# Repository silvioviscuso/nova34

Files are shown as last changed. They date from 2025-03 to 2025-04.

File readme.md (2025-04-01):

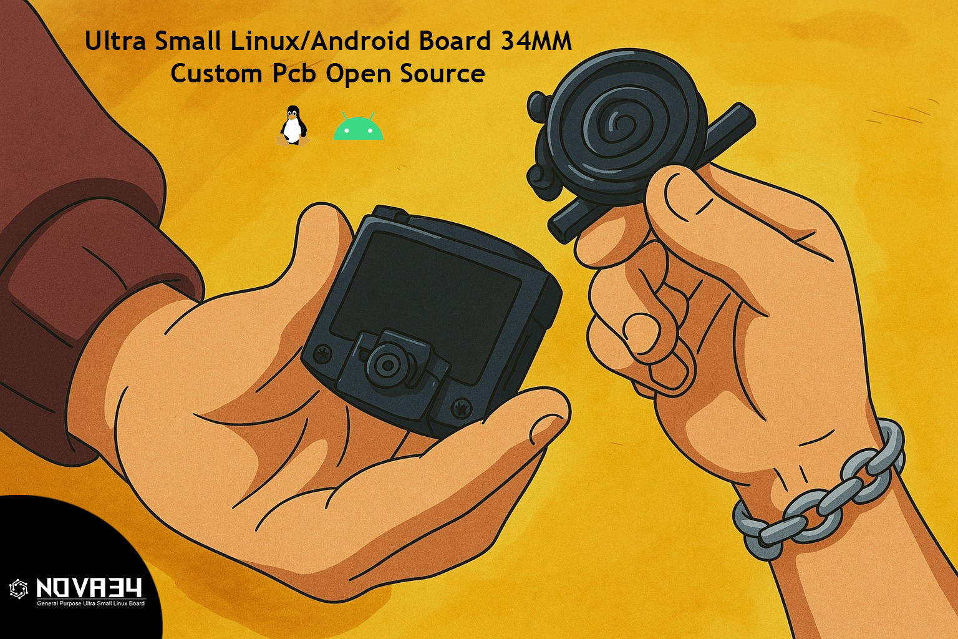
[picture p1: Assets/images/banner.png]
Preview


# NOVA34 Ultra Small Linux Board - Custom PCB Open Source 🚀
      

## Overview
This is an open-source headboard custom PCB designed in Altium for integration with the NXP MIMX8MN5DVPIZAA (I.MX 8M NANO - ULTRALIGHT 11x11MM 14nm). The board is designed to support essential peripherals such as eMMC storage, LPDDR4X RAM, WiFi/Bluetooth, camera module, and display. The design is optimized for performance and ease of assembly, with a compact form factor.

🎯 **The goal was to make it accessible to everyone—hobbyists, makers, robotics enthusiasts—without minimum order limitations.** This project follows the workflow of creating an SBC (Single Board Computer), robot board, and wearable device.

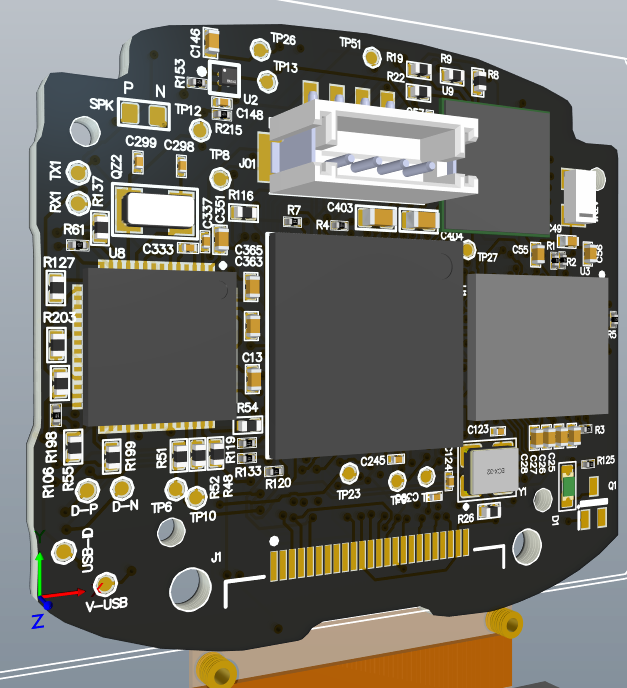
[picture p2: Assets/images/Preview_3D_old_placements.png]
Preview 1
|  | Preview 2 |
|---|---|
###### Preview from Rev_1.3

## 🛠️ Technical Specifications
### 📏 Dimensions
- **Width:** 34mm  
- **Height:** 30.946mm  
- **Thickness:** 1mm  
### Primary Components

#### Back Side
* **NXP MIMX8MN5DVPIZAA** (I.MX 8M NANO - ULTRALIGHT 11x11mm)  
* **PMIC NXP PCA9450BHNY**  
* **Antenna M310220 Kyocera Avx**  
* **ADG824BCPZ-REEL7** (For Antenna Diversity)  
* **Camera 5MP** (Autofocus, 24Pins, around 110° FOV) 
* **Connector JST B4B-ZR-SM4-TF** (1.5mm, 1 Row, 4 Contacts) – Used for power input and serial communication; the same 4-pin header must be present on the new board.  
* **USB Pads for SDM** (Serial Download Mode for firmware flashing)  
* **Speaker Pads and External Speaker**  

###### Combo Chip:  
- **Rev_1.0 to Rev_1.3:** *(Realtek) RTL8723DS* (6x6mm Wi-Fi + Bluetooth)  
- **Final Revision:** *CYW43012* (Infineon)- 106-ball WLBGA (3.76 x 4.43mm; 0.35mm pitch)  
- **Storage:** *(Kingston) 32EP16-M4FTC32-GA68* (eMMC 5.1 HS400 + LPDDR4X 144-FBGA)  

#### Front Side
* **IMU BMI160** Bosch  
* **Display ST0103A2W-WSNLW-F** Santek  
* **NC7SP125P5X** Onsemi Fairchild
* **MAX98357AETE+T**  Analog Device

---

## 🔧 Design and PCB Progress  
#### Revision Notes

In **Rev_1.0 to Rev_1.3**, the process included several testing phases to assess the engineering validity of component research and selection.  

- During this phase, we identified the **ADP191ACBZ-R7**, an ultra-compact high-side load switch. This component could be useful for managing power distribution efficiently, providing controlled power switching to different subsystems while offering short-circuit and overcurrent protection.

- With the latest revision, we implemented the **ADP191ACBZ-R7**,  Now, the **ADP191ACBZ-R7** also provides **ESD protection**, which was previously required only for USB connections. To ensure stable voltages, we added protection for the **CAMERA, DISPLAY, and WIFI module** using the **ADP191ACBZ-R7**. Additionally, we included a differential pair for the USB connection. The **ADP191ACBZ-R7** is now connected with **GPIO pins**, allowing it to be enabled and disabled as needed.

- Additionally, we replaced the **RTL8723DS (6x6mm)** combo-chip Wi-Fi/Bluetooth. Its footprint fit comfortably in the upper-right section of the back-side of the board. However, after further evaluation, we found a better and more compact alternative: the **CYW43012**, which offers improved efficiency and performance.  

- Initially, we also considered the **AMA3B1KK-KBR-B0 (Apollo3 Blue)**, but in the end, we opted for the **CYW43012** as the best choice for this design. That said, we could still explore **future variants** incorporating different wireless solutions based on project needs.  

- Placement and optimization trials were conducted, along with numerous other evaluations, successfully achieving the set objectives.  

- Additionally, for the **RF switch component**, we utilized the **ADG824BCPZ-REEL7** instead of the **QPC8020QTR13 (Qorvo, RF switch)** to support **Antenna Diversity**, which includes both traced and ceramic antenna configurations.  

Now, with the **final revision**, the **schematic is fully defined and accurate**, allowing for a more streamlined approach to PCB design in **High-Speed Design & Signal Integrity**.

---

### Test in old revisions component placements
| Top Signal | Top SilkScreen | Solder Mask |
|---|---|---|
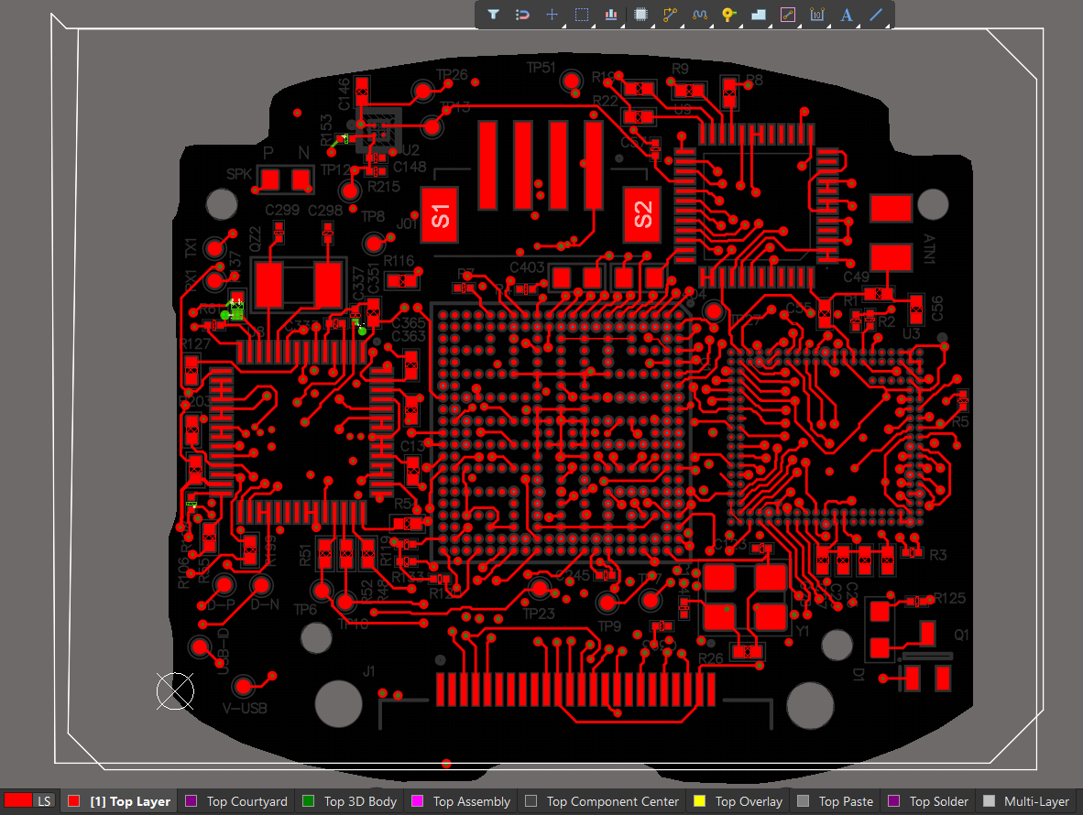
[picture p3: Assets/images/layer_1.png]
Layer 1
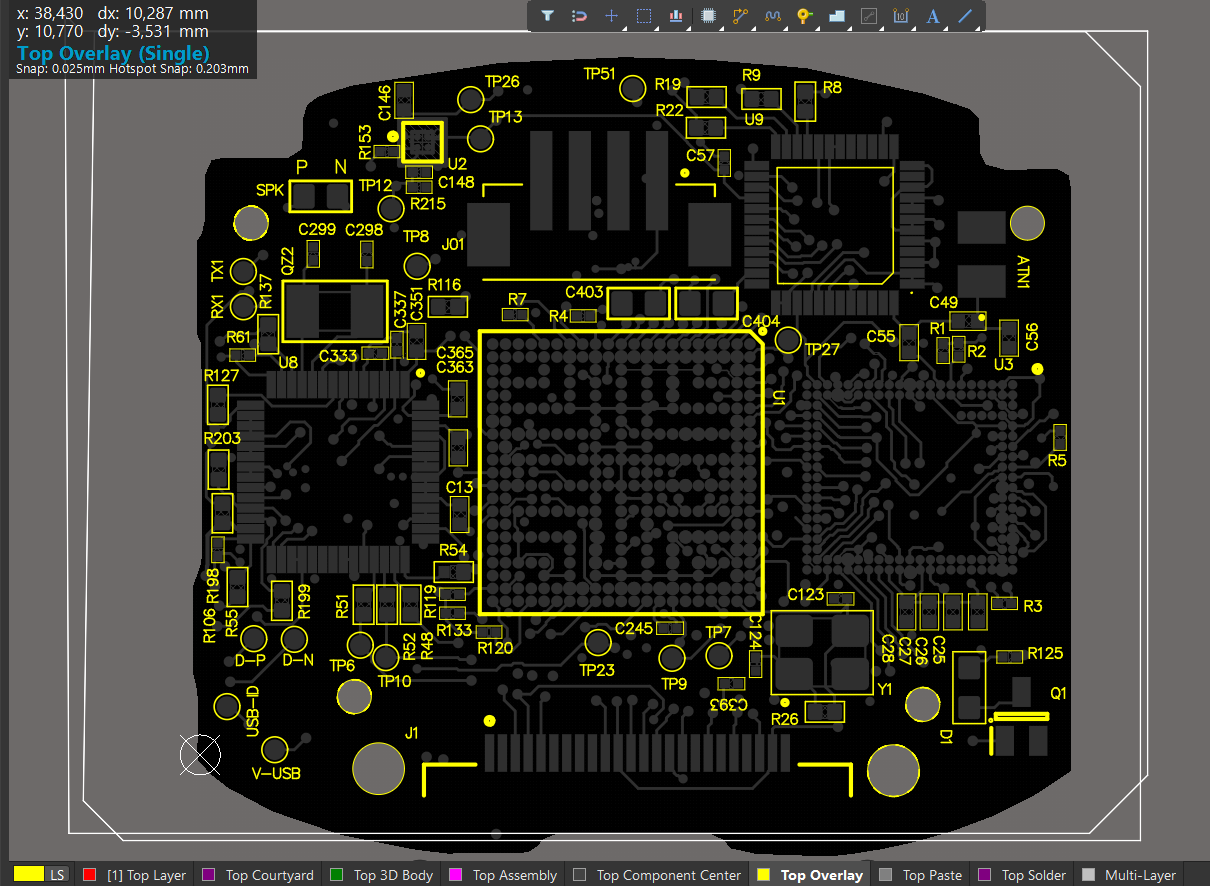
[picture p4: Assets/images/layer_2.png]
Layer 2
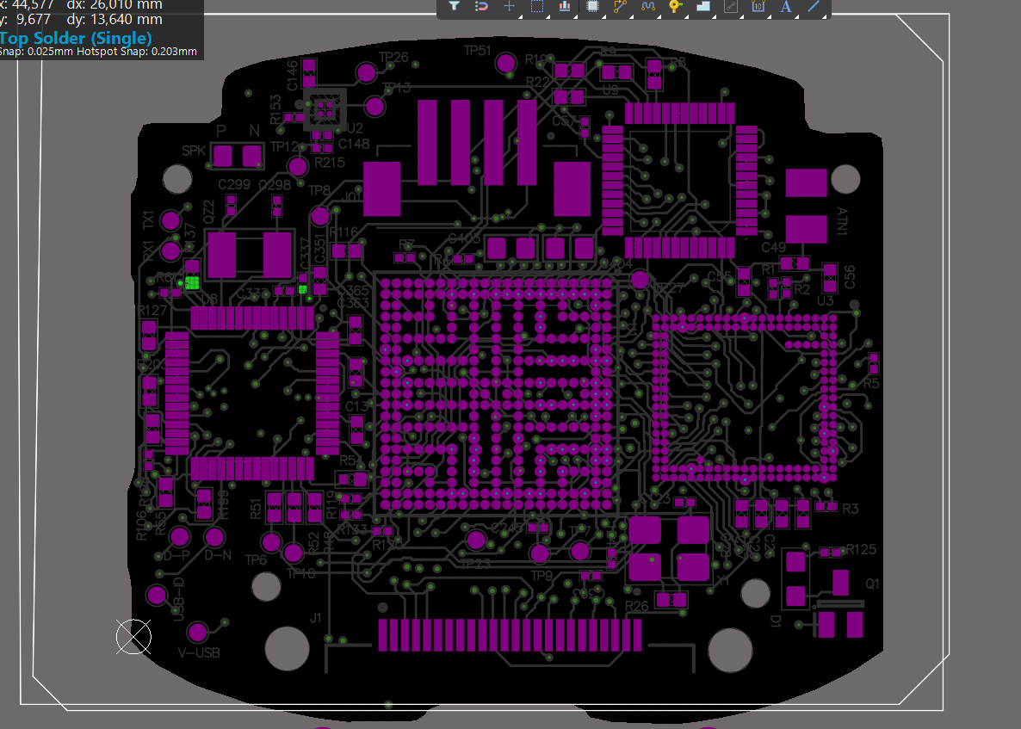
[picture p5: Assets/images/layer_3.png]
Layer 3
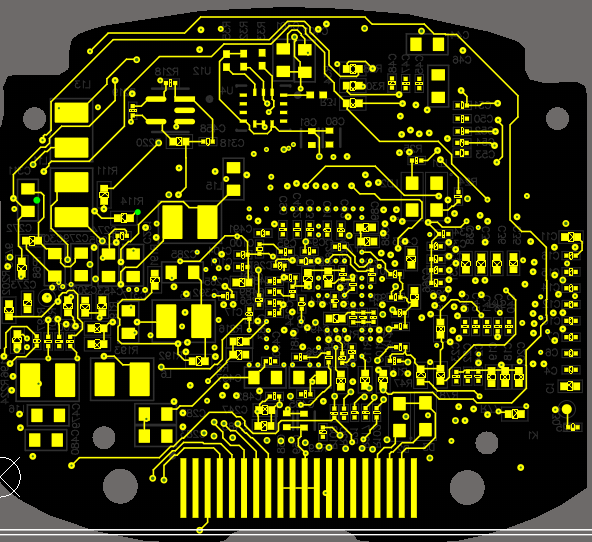
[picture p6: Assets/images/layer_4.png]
Layer 4
|  |  |  |  |

##### Old preview 3D
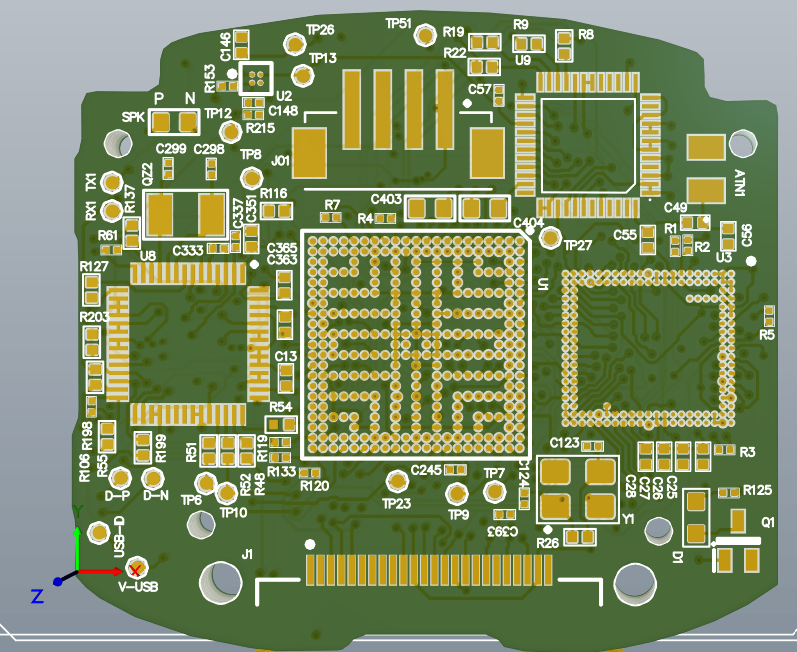
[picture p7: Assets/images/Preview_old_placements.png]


--- 

#### Status:  
**Schematic:** ██████████ 100% (Complete)  
**PCB:** ███░░░░░░░░ 30% (In Progress)

---

## 📋 Component List & Costs (Prices may vary depending on the supplier, market trends or other reasons)
📄 A detailed spreadsheet with reference links (primary components) has been created. You can find it here: [Components/components.md](Components/components.md).
| **Componente** | **Part Number** | **Price (€)** |
|---|---|---|
| **Processor** | MIMX8MN5DVPIZAA  (NXP) | 22.14 |
| **Memory ePOP** | 32EP16-M4FTC32-GA68 (KINGSTON) | 25.35 |
| **Connector** | B4B-ZR-SM4-TF (JST) | 0.66 |
| **PMIC** | PCA9450BHNY (NXP) | 4.11 |
| **IMU** | BMI160 (BOSCH) | 1.46 |
| **WiFi/Bluetooth**  | CYW43012TC0KFFBH  (Infineon Technologies) | 10.00 |
| **Antenna** | M310220  (KYOCERA AVX) | 0.91 |
| **Display** | ST0103A2W-WSNLW-F  (SANTEK DISPLAY SPECIALIST) | 31.84 |
| **DAC** | MAX98357AETE+T (ANALOG DEVICE) | 4.50 |
| **External Speaker**| RS PRO 8Ω 0.5W Miniature Speaker 20mm (RS PRO) | 15.00 |
| **RF SWITCH** | ADG824BCPZ-REEL7 (ANALOG DEVICE) | 3.00 |
| **Buffer** | NC7SP125P5X (Onsemi Fairchild) | 0.70 |
| **Camera** | 5MP MIPI Camera Module – MCM5M120M6F1 (IADY) | 15.00 (USD) |
| **Power Switch** | ADP191ACBZ-R7 (ANALOG DEVICE) | 1.91 (USD) |
| **PCB + Stencil**  | JLPCB | 120-150 |

---

### Requirements:
- Software: Altium Designer v24.6.1 or later. (Fully compatible with **MacOS via Parallels Desktop with Windows 11 ARM**).

---

## 🚀 Getting Started  

#### The official documentation can be found in the nova34_docs repository at the following link: [nova34-docs.vercel.app](https://nova34-docs.vercel.app)

1. **Download the Design Files**  
   - [GitHub Repository](https://github.com/silvioviscuso/nova34)  
   - Open Project group file (**.Nova.DsnWrk**)

2. **Schematics, Library and Netlist**  
   - At this stage, the **schematic files, library, and netlist** are fully completed and ready for review.  
   - The **PCB design is still in progress**, and full assembly instructions will be provided once completed.  

3. **Upcoming Documentation** *(to be released soon)*  
   - Complete **PCB assembly guide** for both factory production and **homemade/hobbyist assembly**.  
   - **List of required tools** for manual assembly.  
   - **Technical drawings** and reference materials.  
   - **Decals and labeling** for easy identification.  
   - Additional resources to streamline the build process.  
---

## 🤝 Contributing
This project is open-source, and contributions are welcome! You can help by:
- Suggesting improvements or fixes.
- Testing and documenting.
- Creating alternative designs or add-ons.
- Developing a custom jig with pogo pins.
- Generating an interactive BOM (HTML/PDF).
- Designing a high-speed circuit with signal integrity considerations.
- Performing thermal simulations.

We encourage you to submit a pull request with your contributions to help improve the project!

### How to Submit a Pull Request
1. **Fork the repository** to your GitHub account.
2. **Create a new branch** dedicated to your revision (e.g., `Rev_1.4-fix-component-placement`).
3. **Make your changes** and ensure everything works as expected.
4. **Commit and push** your changes to your forked repository.
5. **Open a pull request** with a clear description of the modifications and improvements.

## ⭐ Star project and stay tuned for updates!

## 📜 License
This project is released under the **Creative Commons Attribution-NonCommercial 4.0 International (CC BY-NC 4.0) License**. You are free to modify and share the design, but **commercial use is not permitted**.

---
## 🔗 Other Similar Projects  

If you're interested in open-source compact boards and embedded devices, you might also find this project useful:  

 Chip Icon&nbsp; **[ESP32-REACTJS-DEVKIT](https://github.com/silvioviscuso/ESP32-REACTJS-DEVKIT)** – An **ultra-compact 35mm board** based on **ESP32-DOWDQ6 + 16MB**, perfect for IoT projects and ReactJS development.  

---

For any questions or discussions, feel free to open an issue on GitHub or contact me directly.

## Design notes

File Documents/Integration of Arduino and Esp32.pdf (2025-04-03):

### Integration of Arduino with MX8M

Integrating Arduino into this project isn’t about replacing the i.MX 8M Nano; it’s about adding an accessible, flexible layer that our community can readily work with. Here’s how Arduino relevance is achieved:

1. Task Offloading & Peripheral Expansion:
Arduino boards can handle low-level, time-critical tasks (like sensor readings, motor control, and managing extra GPIOs) so the main Nano can focus on high-performance tasks such as multimedia processing. This means hobbyists and makers can add new peripherals (sensors, actuators, etc.) and control them via Arduino, leveraging its rich library ecosystem.

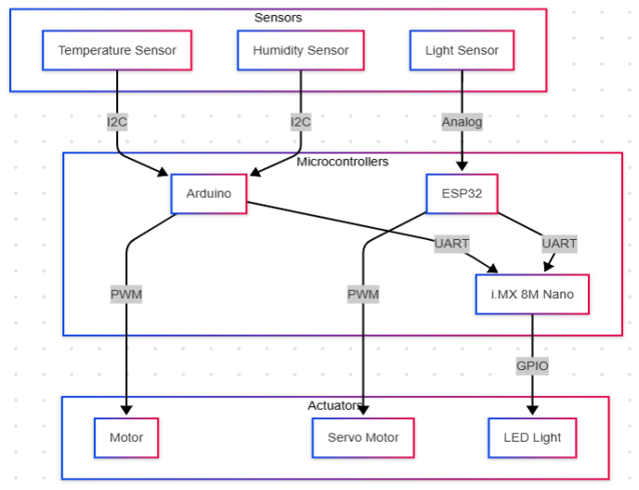
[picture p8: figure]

2. Ease of Use & Rapid Prototyping:
Arduino’s well-documented programming environment makes it straightforward for the community to experiment, develop new applications, and quickly integrate additional functionalities without having to dive into complex C-code for the Nano. For instance, you can use a dedicated Arduino-compatible header (via a JST connector) for serial communication, allowing users to send commands, debug, or control aspects of the board easily.
3. Interoperability:
The design allows the Arduino (or even an ESP32 module) to act as a co-processor. This modular approach means that Arduino can be used to bridge legacy projects or quick prototypes with the high-performance NOVA34 system. Whether it’s handling local sensor data or managing simple automation tasks, the Arduino integration makes the platform more accessible to a broader community.

### Arduino Integration

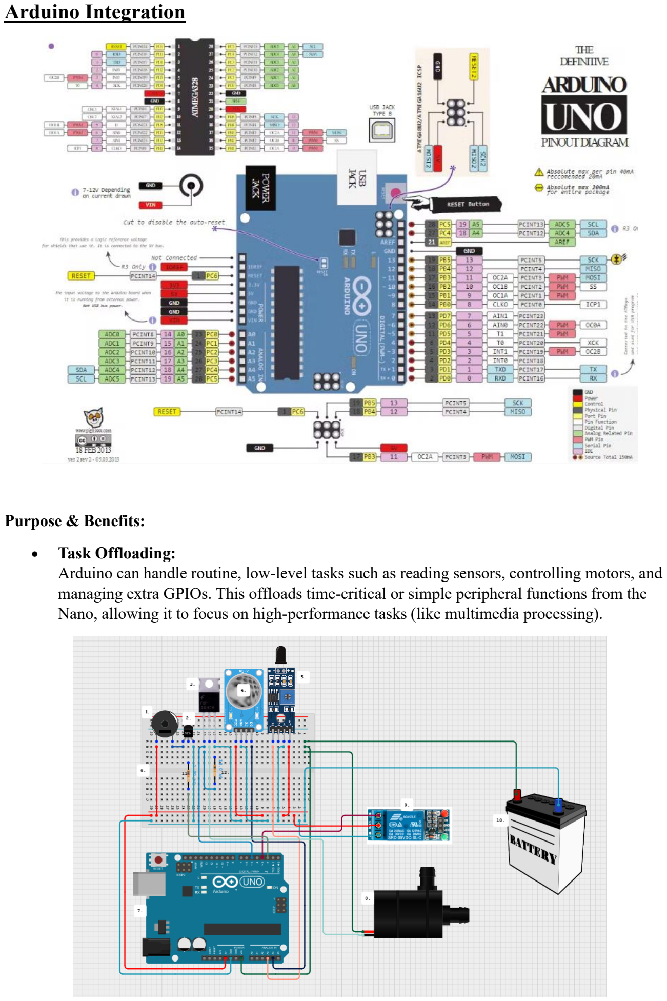
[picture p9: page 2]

Purpose & Benefits:

- Task Offloading:
Arduino can handle routine, low-level tasks such as reading sensors, controlling motors, and managing extra GPIOs. This offloads time-critical or simple peripheral functions from the Nano, allowing it to focus on high-performance tasks (like multimedia processing).

- Rapid Prototyping:
Arduino’s well-documented ecosystem, familiar IDE, and rich library support make it easy for hobbyists to quickly develop and test new ideas. Users can rapidly add functionalities (e.g., environmental sensing, actuator control, or even simple user interfaces) without diving into complex low-level code.
- Interoperability:
Arduino modules can act as co-processors, handling specialized tasks and communicating with the Nano via serial (UART), SPI, or I²C interfaces. For example, a dedicated Arduino header (using a JST connector) can allow users to send serial commands, debug the system, or control external peripherals independently.

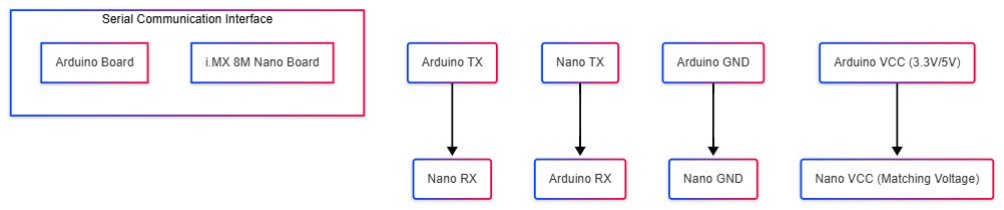
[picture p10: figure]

What Arduino Can Control:

- Sensors and Actuators: Arduino can manage additional sensors (temperature, humidity, light, etc.) and drive actuators (motors, LEDs, relays) using its digital I/O, analog inputs, and PWM outputs.
- User Interfaces: It can handle button inputs, LED displays, or even small OLED screens to create custom user interfaces or status indicators.
- Communication Protocols: Arduino can take over I²C, SPI, or UART communications for non-critical peripherals, freeing up the Nano’s resources.

### 2. ESP32 Integration

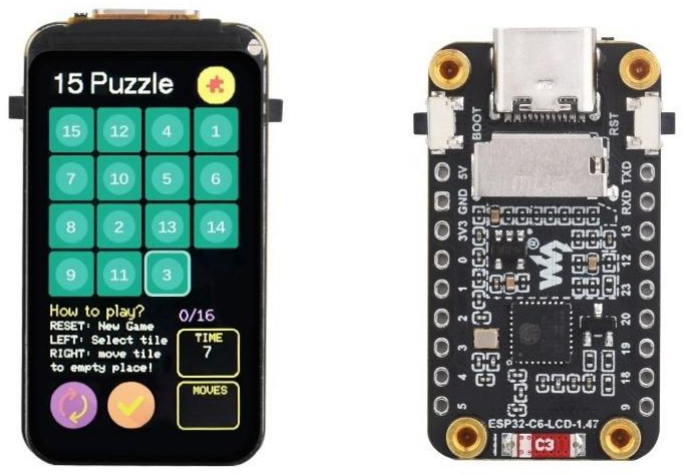
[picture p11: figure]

Purpose & Benefits:

- Enhanced Wireless Connectivity:
While the CYW43012 handles Wi-Fi/Bluetooth for the main system, the ESP32 can serve as a backup or additional communication channel. Its built-in Wi-Fi and Bluetooth, along with robust network libraries, make it ideal for IoT applications.

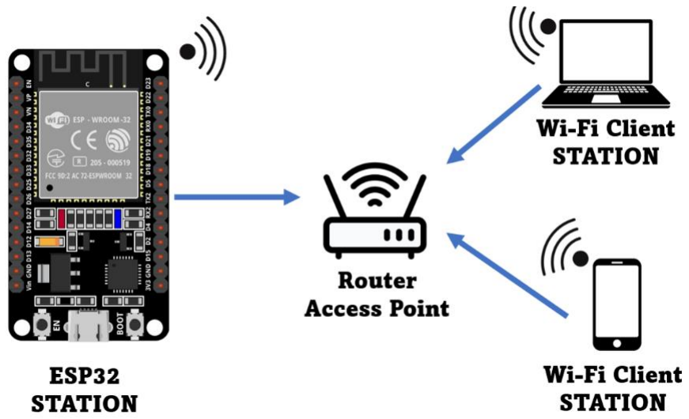
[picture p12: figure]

- Edge Processing:
The ESP32’s dual-core processor can perform local data processing, filter sensor data, or run lightweight machine learning algorithms at the edge. This reduces latency and decreases the processing load on the Nano.
- Intermediary Role:
ESP32 can act as a gateway between the NOVA34 and cloud services, managing local communication protocols, buffering data, or handling over-the-air updates.

What ESP32 Can Control:

- Real-Time Sensor Data Processing: The ESP32 can gather data from sensors connected via I²C, SPI, or analog inputs, process it locally, and then forward critical information to the Nano.

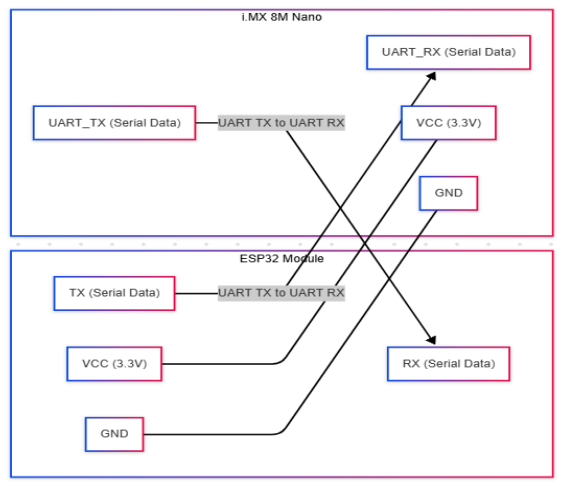
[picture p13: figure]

- Local User Interfaces: ESP32 can drive small displays, manage touch inputs, or even handle audio tasks for voice commands.
- Secondary Communication Interfaces: It can manage additional interfaces like secondary UARTs or SPI buses, especially useful when connecting legacy devices or creating a modular expansion system.

### 3. System Integration & Interfaces

Dedicated Expansion Connectors:

- Serial/JST Connector:
A dedicated 4-pin JST header on the NOVA34 board can provide power and serial communication (TX, RX) between the Nano and an Arduino or ESP32 module. This interface allows for command/control, debugging, and firmware updates.
- I²C/SPI Buses:
Shared I²C or SPI buses enable both Arduino and ESP32 to interface with external sensors and modules. Level shifting might be necessary if voltage domains differ.
- GPIO Expansion:
Additional GPIO headers can be routed to allow these co-processors to control or monitor extra peripherals without interfering with the Nano.

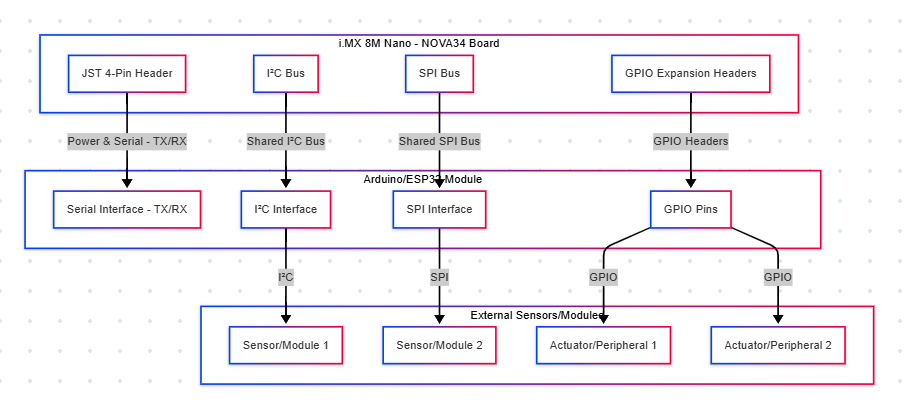
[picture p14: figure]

Software & Communication:

- Inter-Processor Protocols:
Define a clear protocol (for example, using serial commands, MQTT over Wi-Fi, or SPI-based communication) so that Arduino/ESP32 can reliably send data to, or receive commands from, the i.MX 8M Nano.
- Firmware Examples:
Provide sample sketches and libraries that demonstrate how to offload tasks like sensor reading, motor control, and local processing to Arduino/ESP32, with results then communicated back to the main system.
- Community Collaboration:
Document these interfaces extensively in the project’s GitHub repository to encourage community contributions, making it easier for Arduino and ESP32 developers to build on the platform.

### 4. Future Possibilities for Community Extensions

- Modular Sensor Hubs:
Create Arduino shields or ESP32 modules for specific functions (e.g., environmental monitoring, robotics control) that can plug into the NOVA34 system.
- Local Data Processing:
Develop projects where the ESP32 performs preliminary data processing (like filtering or aggregation) before handing off data to the Nano, improving system efficiency.
- Interoperability Projects:
Leverage the familiarity of Arduino and the advanced capabilities of ESP32 to enable projects that span both communities, such as remote monitoring systems, IoT gateways, or hybrid robotics platforms.
- User Interface Development:
Build additional user interface modules that can be controlled independently via Arduino/ESP32, enabling a more versatile, multi-touch, or even voice-controlled system.

Conclusion

Integrating Arduino and ESP32 into the NOVA34 project enriches the platform by offloading simpler, real-time tasks and expanding peripheral connectivity. This approach not only reduces the load on the high-performance i.MX 8M Nano but also opens up a broad range of possibilities for rapid prototyping, community-driven innovation, and modular expansion. By providing dedicated interfaces—such as serial headers, shared I²C/SPI buses, and additional GPIOs—the project becomes more accessible to both Arduino and ESP32 communities, ensuring that a wide range of applications and modifications can be explored.

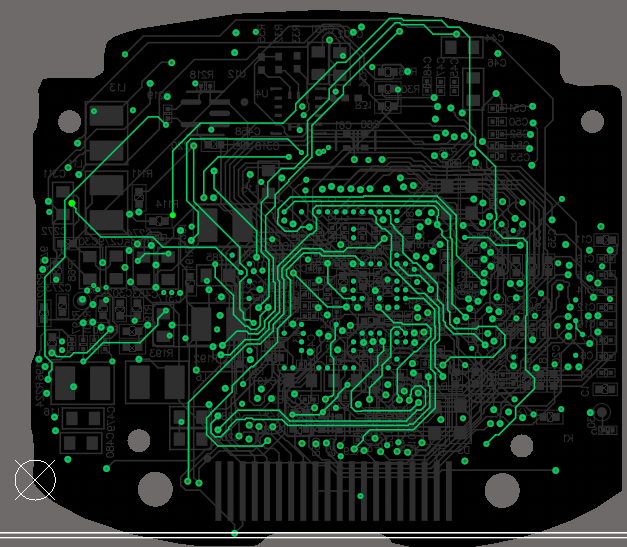
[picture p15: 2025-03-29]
Assets/images/layer_5.png

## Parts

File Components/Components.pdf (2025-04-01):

### Components

01/04/2025 20.48.29

Component Name | Description | Datasheet Link | Purchase Link
ST0103A2W-WSNLW-F_A04 | Display Oled | http://www.santechnology.com/pdf/Digikey/Standard%20TFT/ST0103A2W-WSNLW-F.pdf https://it.aliexpress.com/i/1005006103666704.html
BMI160 | IMU 6-Axis | Datasheet & Ecad Mouser Link (https://www.mouser.it/ProductDetail/Bosch-Sensortec/BMI160?qs=Lj1LZLjqIN1DEsUDgjehlg%3D%3D) | https://it.aliexpress.com/item/1005006347655050
NXP MIMX8MN5DVPIZAA | CPU+AI Co-Processor | https://www.mouser.it/datasheet/2/302/IMX8MNCEC-2256506.pdf https://www.mouser.it/ProductDetail/NXP-Semiconductors/MIMX8MN5DVPIZAA
NXP PCA9450BHNY | PMIC | https://www.mouser.it/datasheet/2/302/PCA9450-3420300.pdf https://www.mouser.it/ProductDetail/NXP-Semiconductors/PCA9450BHNY
M310220 Kyocera Avx | Ceramic Antenna (w/b) | https://www.mouser.it/datasheet/2/40/AVX_E_M310220-3313042.pdf https://www.mouser.it/ProductDetail/KYOCERA-AVX/M310220
ADG824BCPZ-REEL7 | RF Switch for antenna diversity | https://www.mouser.it/datasheet/2/609/ADG824-1503118.pdf https://www.mouser.it/ProductDetail/Analog-Devices/ADG824BCPZ-REEL7
Mini Camera 5MP | Autofocus, around 110° FOV | https://www.iadiy.com/MCM5M120M6F1.pdf (https://www.iadiy.com/image/catalog/IADIY/products/camera-module/mipi-camera-module/MIPI-camera-sensor-module-MCM5M120M6F1.pdf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) | https://www.iadiy.com/camera-module/MIPI-camera-module
JST B4B-ZR-SM4-TF | Connector | https://www.jst.com/products/insulation-displacement-connectors-wire-to-board-type/zr-connector/ https://www.digikey.it/it/products/detail/jst-sales-america-inc/B4B-ZR-SM4-TF
RS PRO - Miniature Speaker | External Speaker | https://docs.rs-online.com/673f/0900766b8168e0df.pdf https://uk.rs-online.com/web/p/miniature-speakers/1797441
NC7SP125P5X | Buffer | https://www.onsemi.com/PowerSolutions/product.do?id=NC7SP125P5X https://www.mouser.it/ProductDetail/onsemi-Fairchild/NC7SP125P5X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
MAX98357AETE+T | DAC | https://www.mouser.it/datasheet/2/609/1/MAX98357A_MAX98357B-3471189.pdf https://www.mouser.it/ProductDetail/Analog-Devices-Maxim-Integrated/MAX98357AETE+T
ADP191ACBZ-R7 | power switch, control power | https://www.mouser.it/datasheet/2/609/ADP190_191-1503397.pdf https://www.mouser.it/ProductDetail/Analog-Devices/ADP191ACBZ-R7?qs=WIvQP4zGaniqVZQregMmwA%3D%3D

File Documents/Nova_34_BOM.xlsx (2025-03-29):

Comment | Description | Designator | Footprint | LibRef | Quantity
M310220 | Antennas WiFi/BT Ceramic | ANT1, ANT2, ANT3, ANT4 | M310220 | M310220 | 4
10uF /6.3V/ 0402 | Multilayer Ceramic Capacitors MLCC - SMD/SMT 10 uF 6.3 VDC 20% 0402 X5R | C1, C4, C5, C14, C15, C16, C33, C36, C37, C51, C52, C55, C59, C85, C86, C87, C88, C98, C99, C100, C101 | CAPC1005X65N | GRM155R60J106ME15D | 21
0.22uF /10V/ 0201 | Multilayer Ceramic Capacitors MLCC - SMD/SMT 0201 10VDC 0.22 F 10 X6S | C2, C3, C6, C8, C9, C11, C12, C13, C20, C21, C22, C30, C31, C32, C34, C35, C38, C39, C76, C77, C78, C79, C81, C82, C83, C84, C89, C90, C91, C92, C94, C95, C96, C97, C102, C103, C104, C105 | GRM033D70J224ME01D | GRM033C81A224KE01J | 38
1uF /6.3V/ 0201 | Multilayer Ceramic Capacitors MLCC - SMD/SMT 1 uF 6.3 VDC 20% 0201 X6S | C7, C17, C18, C19, C40, C41, C42, C43, C44, C45, C47, C61, C65, C66, C68, C72, C73 | GRM033D70J224ME01D | GRM033C80J105ME05J | 17
4.7uF /10V/ 0402 | Multilayer Ceramic Capacitors MLCC - SMD/SMT 0402 X6S 4.7 F 20 10VDC AEC-Q200 | C10, C58, C62, C67, C75, C80, C93, C106, C107, C108, C109, C110, C111 | CAPC1005X70N | GRT155C81A475ME13J | 13
22uF /10V/ 0603 | Multilayer Ceramic Capacitors MLCC - SMD/SMT 22 uF 10 VDC 20% 0603 X5R | C23, C24, C25, C26, C27, C28, C29, C50, C53, C54, C56, C57, C60, C63, C64 | GRM18x | GRM187R61A226ME15D | 15
2.2nF /10V/ 0402 | Multilayer Ceramic Capacitors MLCC - SMD/SMT 2200 pF 10 VDC 10% 0402 X5R | C46, C71 | CAPC1005X70N | GRM155R61A222KA01D | 2
12pF | Capacitor | C48, C49 | CAPC0603X33N | CGA1A2C0G1E120J030BA | 2
18pF | Capacitor | C69, C70 | CAPC0603X33N | GRM0335C1H180JA01D | 2
GRM0335C1H180JA01D | Capacitor | C74 | CAPC0603X33N | GRM0335C1H180JA01D | 1
0.1uF /0402 | Capacitor | C112, C113, C114, C115 | CAPC1005X70N | GRM155R71C104KA88D | 4
MCM5M120M6F1 | MCM5M120M6F1 is a cost effective 5 Mega Pixel MIPI camera module with an M6 lens slot. | CAM1 | MCM5M120M6F1 | MCM5M120M6F1 | 1
MAX98357AETE+T | Integrated Circuit | IC1 | QFN50P300X300X80-17N | MAX98357AETE+ | 1
JTAG |  | J1, J2, J3 | JTAG | JTAG | 3
1X2 | Connector | J4 | HDRV2W64P0X254_1X2_508X254X838P | TSW-102-07-G-S-002 | 1
1X4 | Connector | J5 | B4BZRSM4TFLFSN | B4B-ZR-SM4-TF_LF__SN_ | 1
ST0103A2W |  | K1 | Display | ST0103A2W | 1
0.47UH | 470 nH Shielded Drum Core, Wirewound Inductor 4.1 A 32mOhm Max 1008 (2520 Metric) | L1, L2, L3, L4, L5, L6 | IND_SPH2520 | WPN252012ER47MT | 6
598-8070-107F | LED | LED1, LED2 | 5988070107F | 598-8070-107F | 2
Speaker-Pad |  | PAD1 | Speaker-Pad | Speaker-Pad | 1
100K /0201 | Resistor | R1, R2, R3, R4, R6 | ERJ1GJJ2R4C | ERJ-1GJF1003C | 5
510k | Resistor | R5 | ERJ2RKD1004X | ERJ-2GEJ514X | 1
240 ohm | Resistor | R7, R17, R18, R19 | RESC0603X26N | RC0201FR-07240RL | 4
0 ohm/0402 | RES MF ZERO OHM 1/16W 5% 0402 | R8, R9, R10, R11, R12, R13, R14, R15, R16 | RES_0402 | RC0402JR-070RL | 9
10K Ohm | Resistor | R20, R21, R22, R23, R24, R25, R26, R27, R28, R29 | RESC1005X40N | RC0402FR-0710KL | 10
EVP-AF5B70 | Switch | S1 | EVPAF5B70 | EVP-AF5B70 | 1
MIMX8MN5CVPIZAA | IC CPU QUAD CORTEX A53+M7 1.4GHZ -- BGA306 | U1 | BGA306C50P21X21_1100X1100X101 | MIMX8MN | 1
PCA9450BHN | IC POWER MANAGEMENT 2.7-5.5V HVQFN56 | U2 | QFN40P700X700X100-57N-D | PCA9450_HVQFN56P_A | 1
32EP16 |  | U3 | BGA144C40P19X21_800X950X80 | 32EP16 | 1
ADG824BCPZ-REEL7 | IC SWITCH SPDTX2 800MOHM 10LFCSP | U4 | ADG824 | ADG824BCPZ-REEL7 | 1
Wifi/BL |  | U5 | 106 BALL WLBGA 3.76X4.43X0.53 MM | CYW43012 | 1
BMI160 | Accelerometer, Gyroscope, 6 Axis Sensor IÂ²C, SPI Output | U6 | PQFN50P250X300X88-14N | BMI160 | 1
TSX-3225_24.0000MF15X-AC3 | Crystal or Oscillator | Y1 | TSX3225240000MF15XAC3 | TSX-3225_24.0000MF15X-AC3 | 1
ABS07-32.768KHZ-T | Crystal or Oscillator | Y2, Y3 | ABS07 | ABS07-32.768KHZ-T | 2

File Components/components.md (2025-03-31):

## 📌 Components

### Introduction 🚀

Welcome to the **Title Datasheet - ECAD** section! Here, you will find a well-organized collection of all the main components used in the project, along with links to their respective datasheets. This document will help you quickly access the necessary information to better understand and utilize the electronic components.

Check the table below to directly access the datasheets of key components. 🔍

Check file [Components.xls](components/Components.xls) or [Components.pdf](components/Components.pdf) 

📂 **Note**: This list will be continuously updated with new components and additional information. Stay tuned! ⚡

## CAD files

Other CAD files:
Shape/DWG/shape.dwg
Hardware/Rev_A.1.5-STABLE/Nova_34/Project Outputs for Free Documents/CalayNetlist/Nova_34.PRT
Hardware/Revisions/Rev_A.1.4-STABLE/Nova_34/Project Outputs for Free Documents/CalayNetlist/Nova_34.PRT

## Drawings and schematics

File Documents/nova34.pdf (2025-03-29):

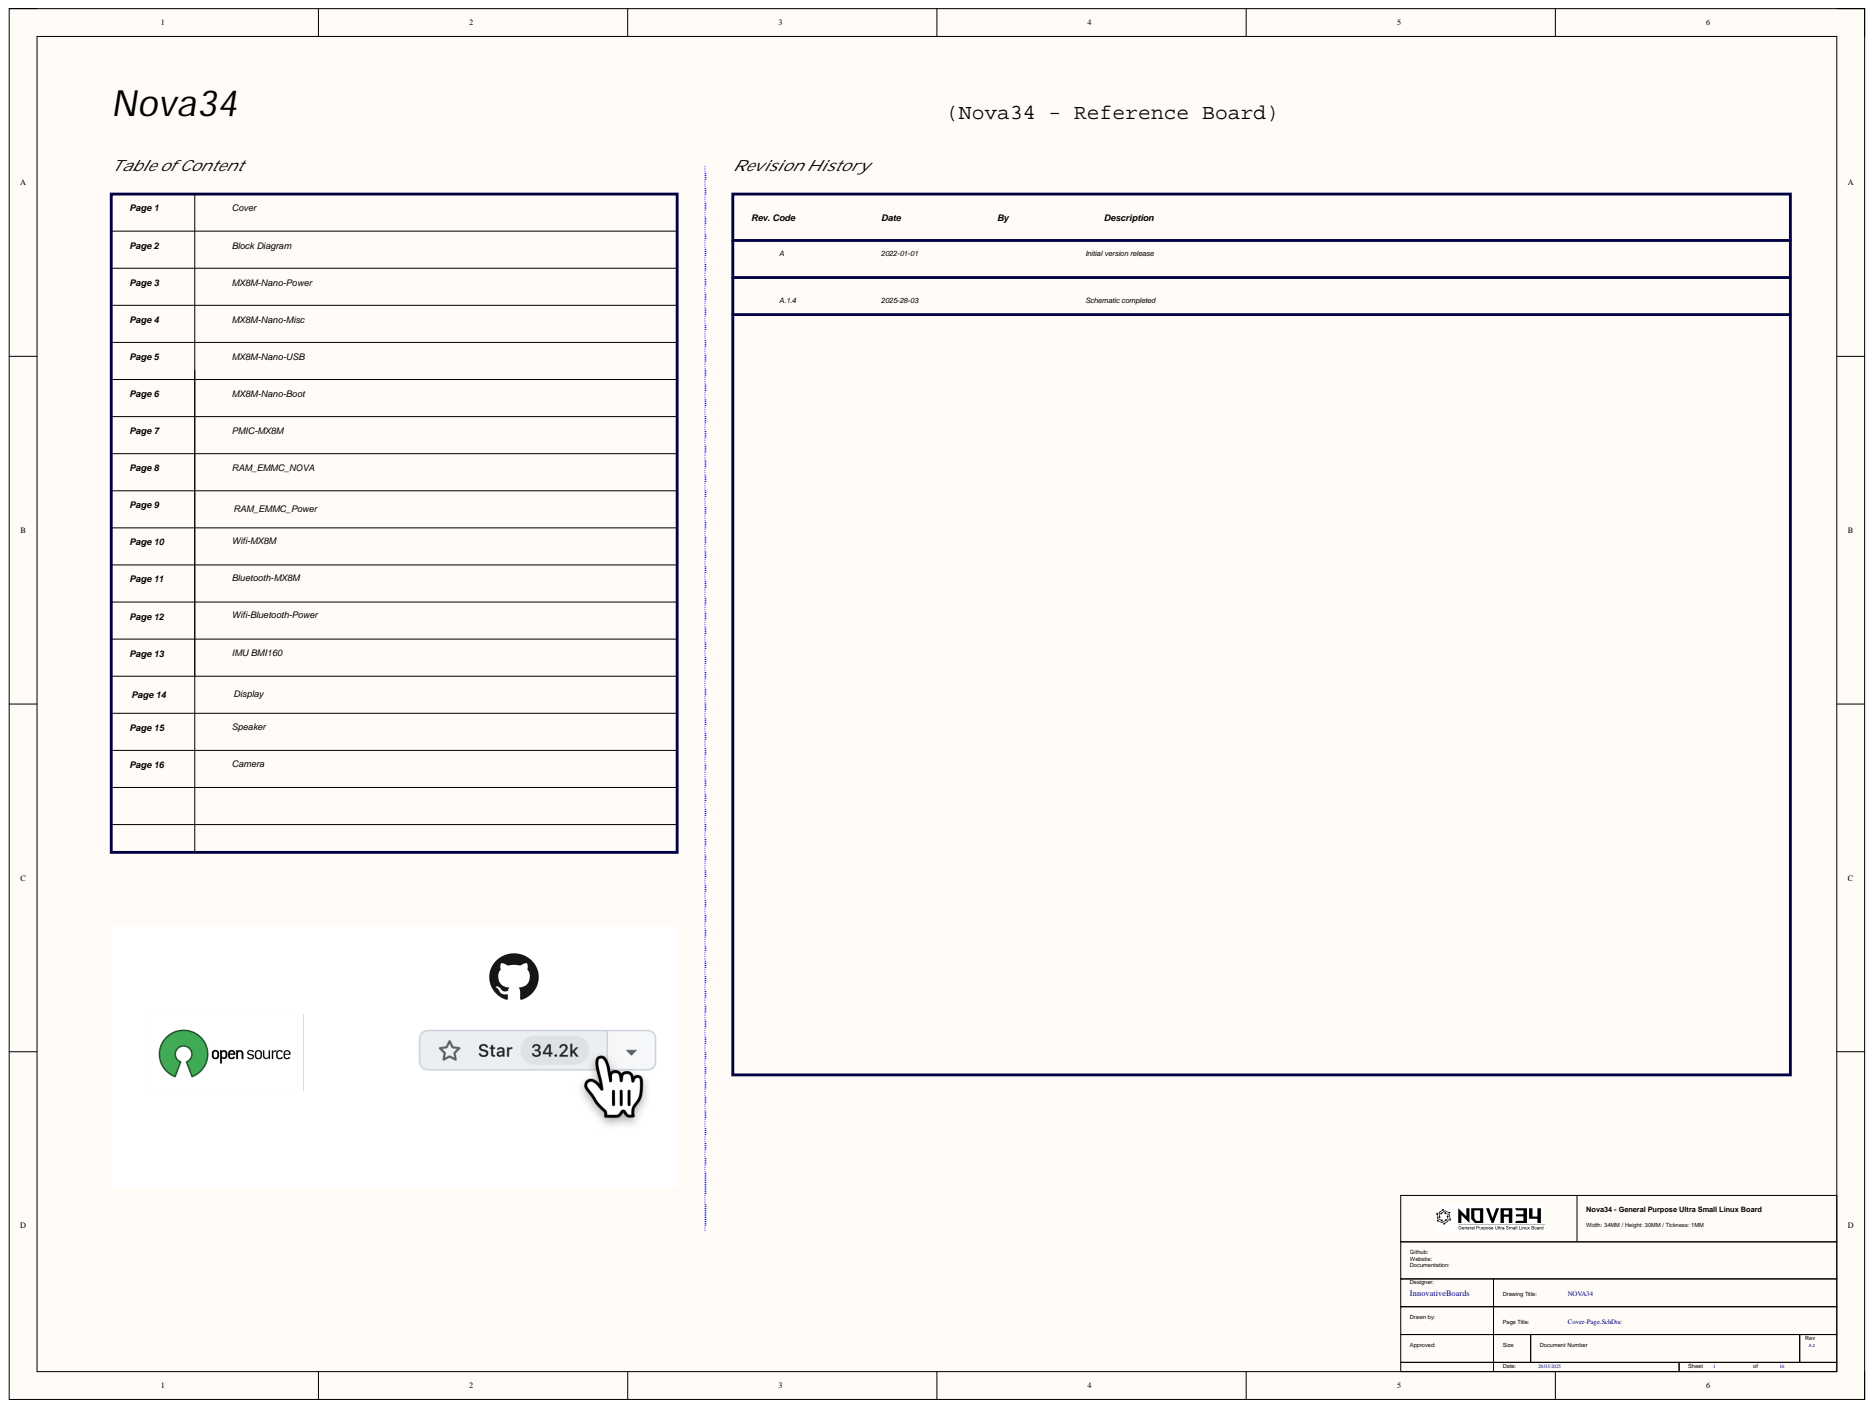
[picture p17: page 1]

Page 2 | Block Diagram

Page 3 | MX8M-Nano-Power

Page 4 | MX8M-Nano-Misc

Page 5 | MX8M-Nano-USB

Page 6 | MX8M-Nano-Boot

Page 7 | PMIC-MX8M

Page 8 | RAM_EMMC_NOVA

Page 9 | RAM_EMMC_Power

Page 10 | Wifi-MX8M

Page 11 | Bluetooth-MX8M

Page 12 | Wifi-Bluetooth-Power

Page 13 | IMU BMI160

Page 14 | Display

Page 15 | Speaker

Page 16 | Camera

Nova34 - General Purpose Ultra Small Linux Board

Designer: InnovativeBoards | Drawing Title: NOVA34

Drawn by: | Page Title: Cover-Page.SchDoc

Approved: | Size | Document Number | Rev A.2

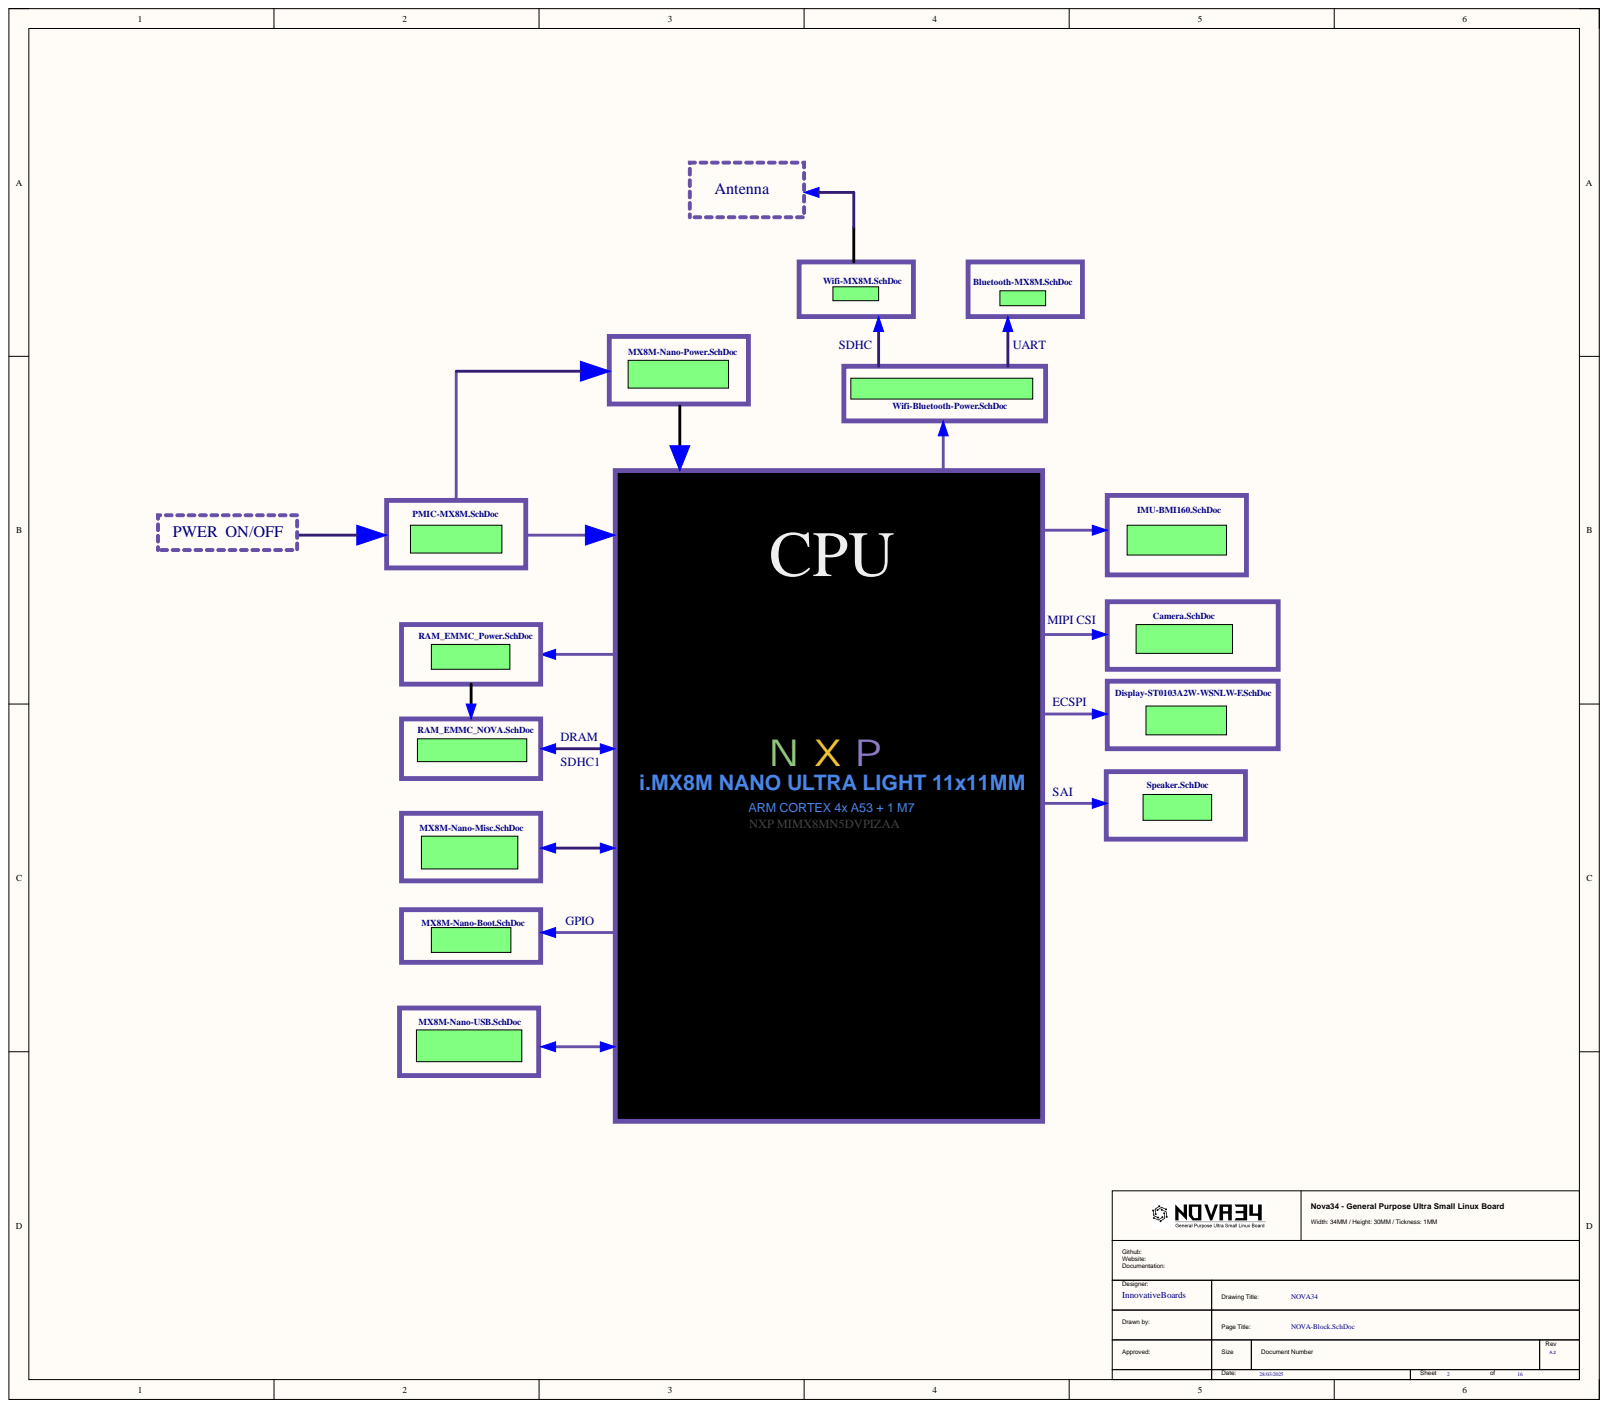
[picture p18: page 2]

Wifi-Bluetooth-Power.SchDoc

Nova34 - General Purpose Ultra Small Linux Board

Designer: InnovativeBoards | Drawing Title: NOVA34

Drawn by: | Page Title: NOVA-Block.SchDoc

Approved: | Size | Document Number | Rev

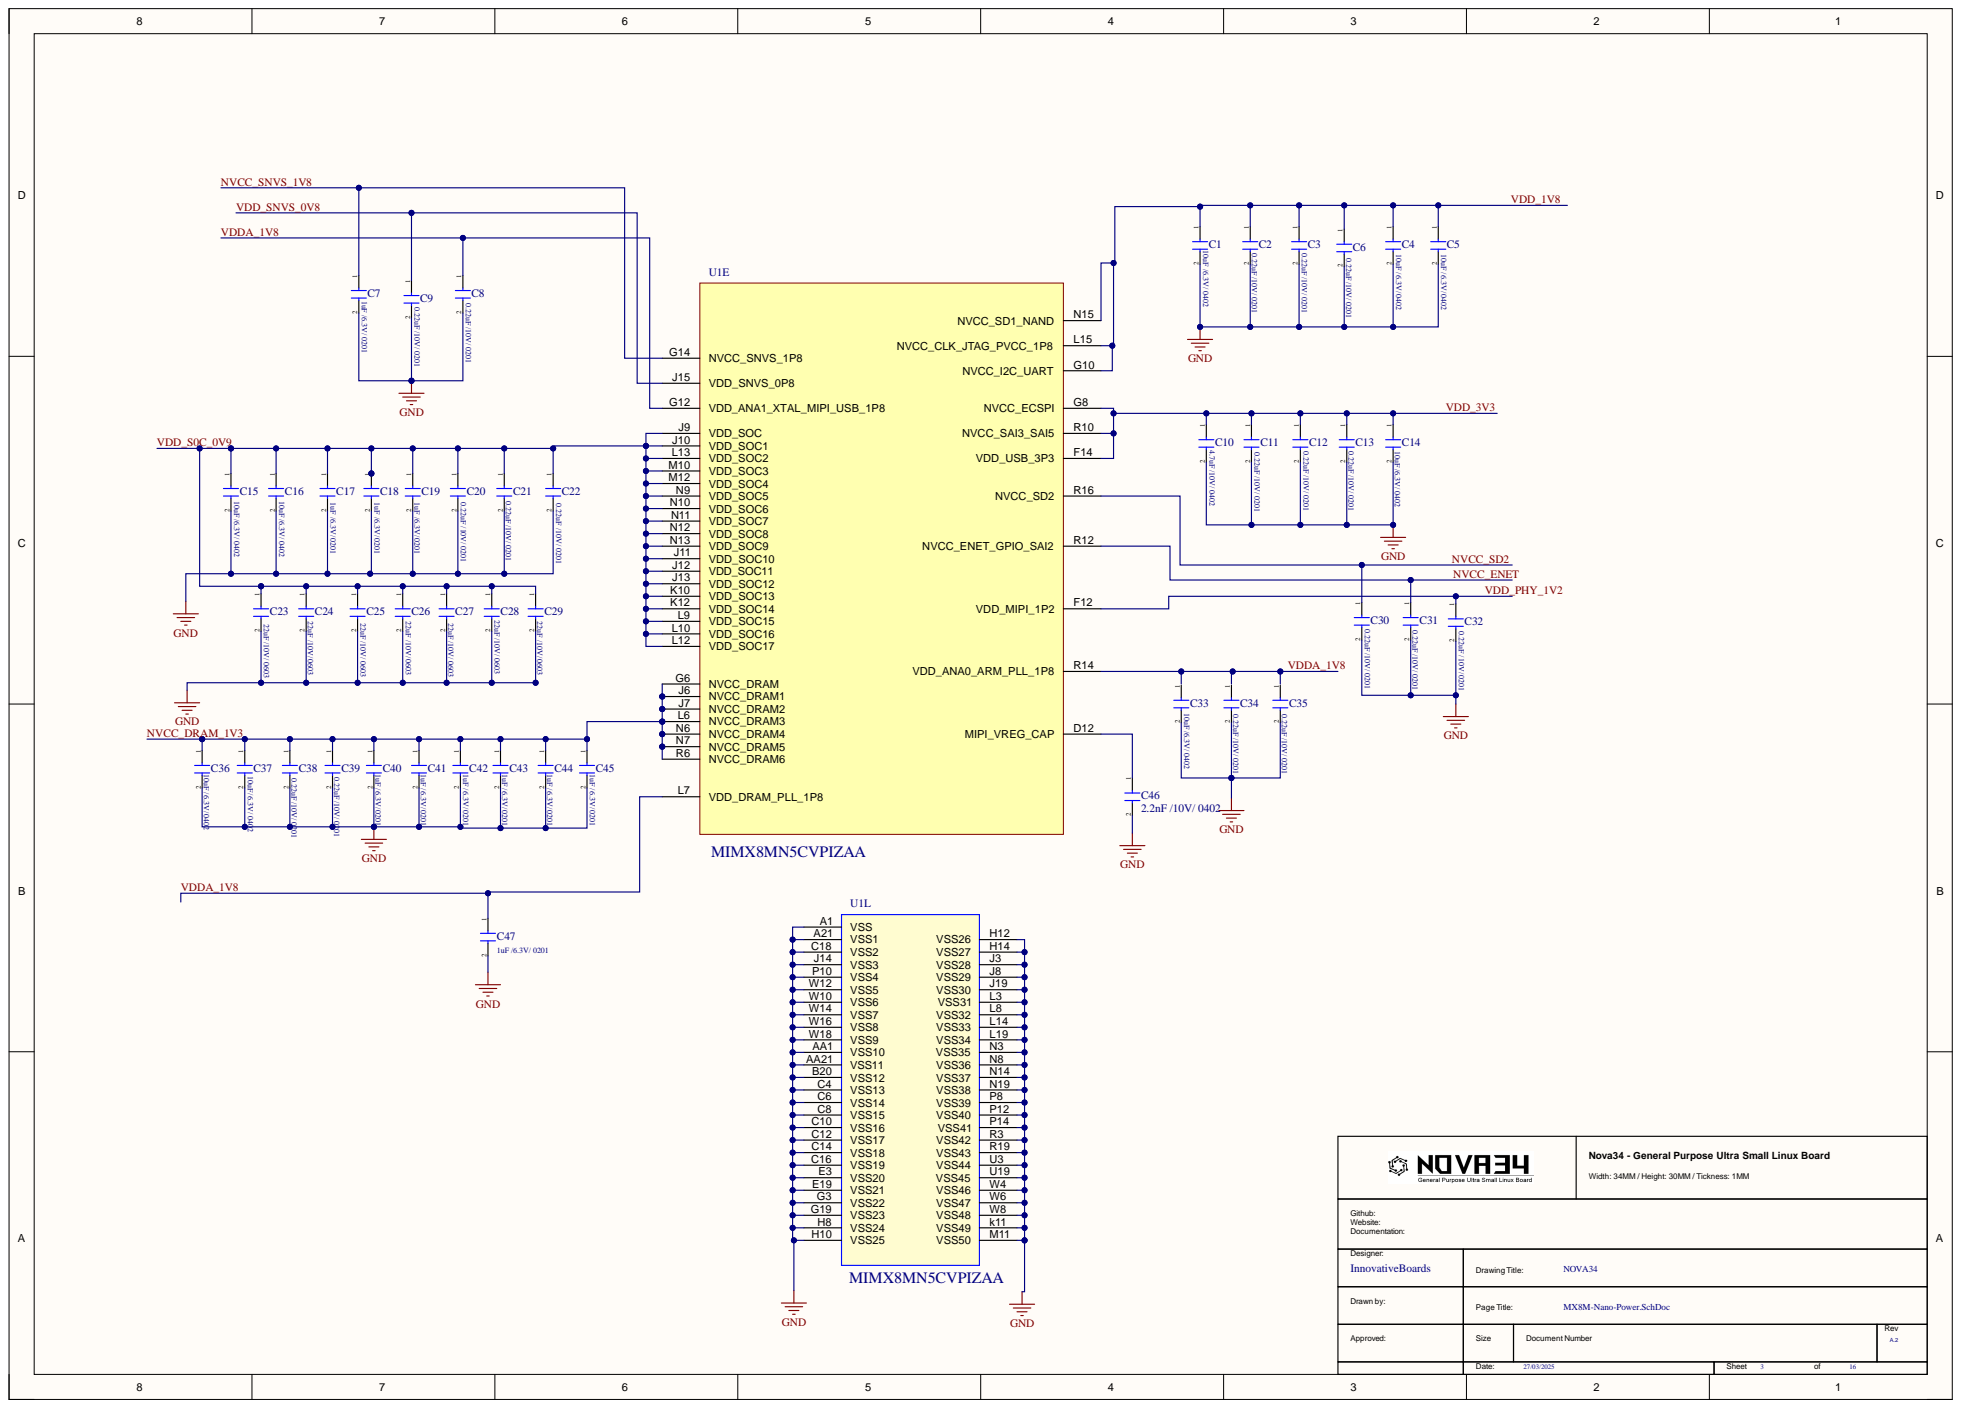
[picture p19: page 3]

VDD_SNVS_0P8 J15

Nova34 - General Purpose Ultra Small Linux Board

Designer: InnovativeBoards | Drawing Title: NOVA34

Drawn by: | Page Title: MX8M-Nano-Power.SchDoc

Approved: | Size | Document Number | Rev

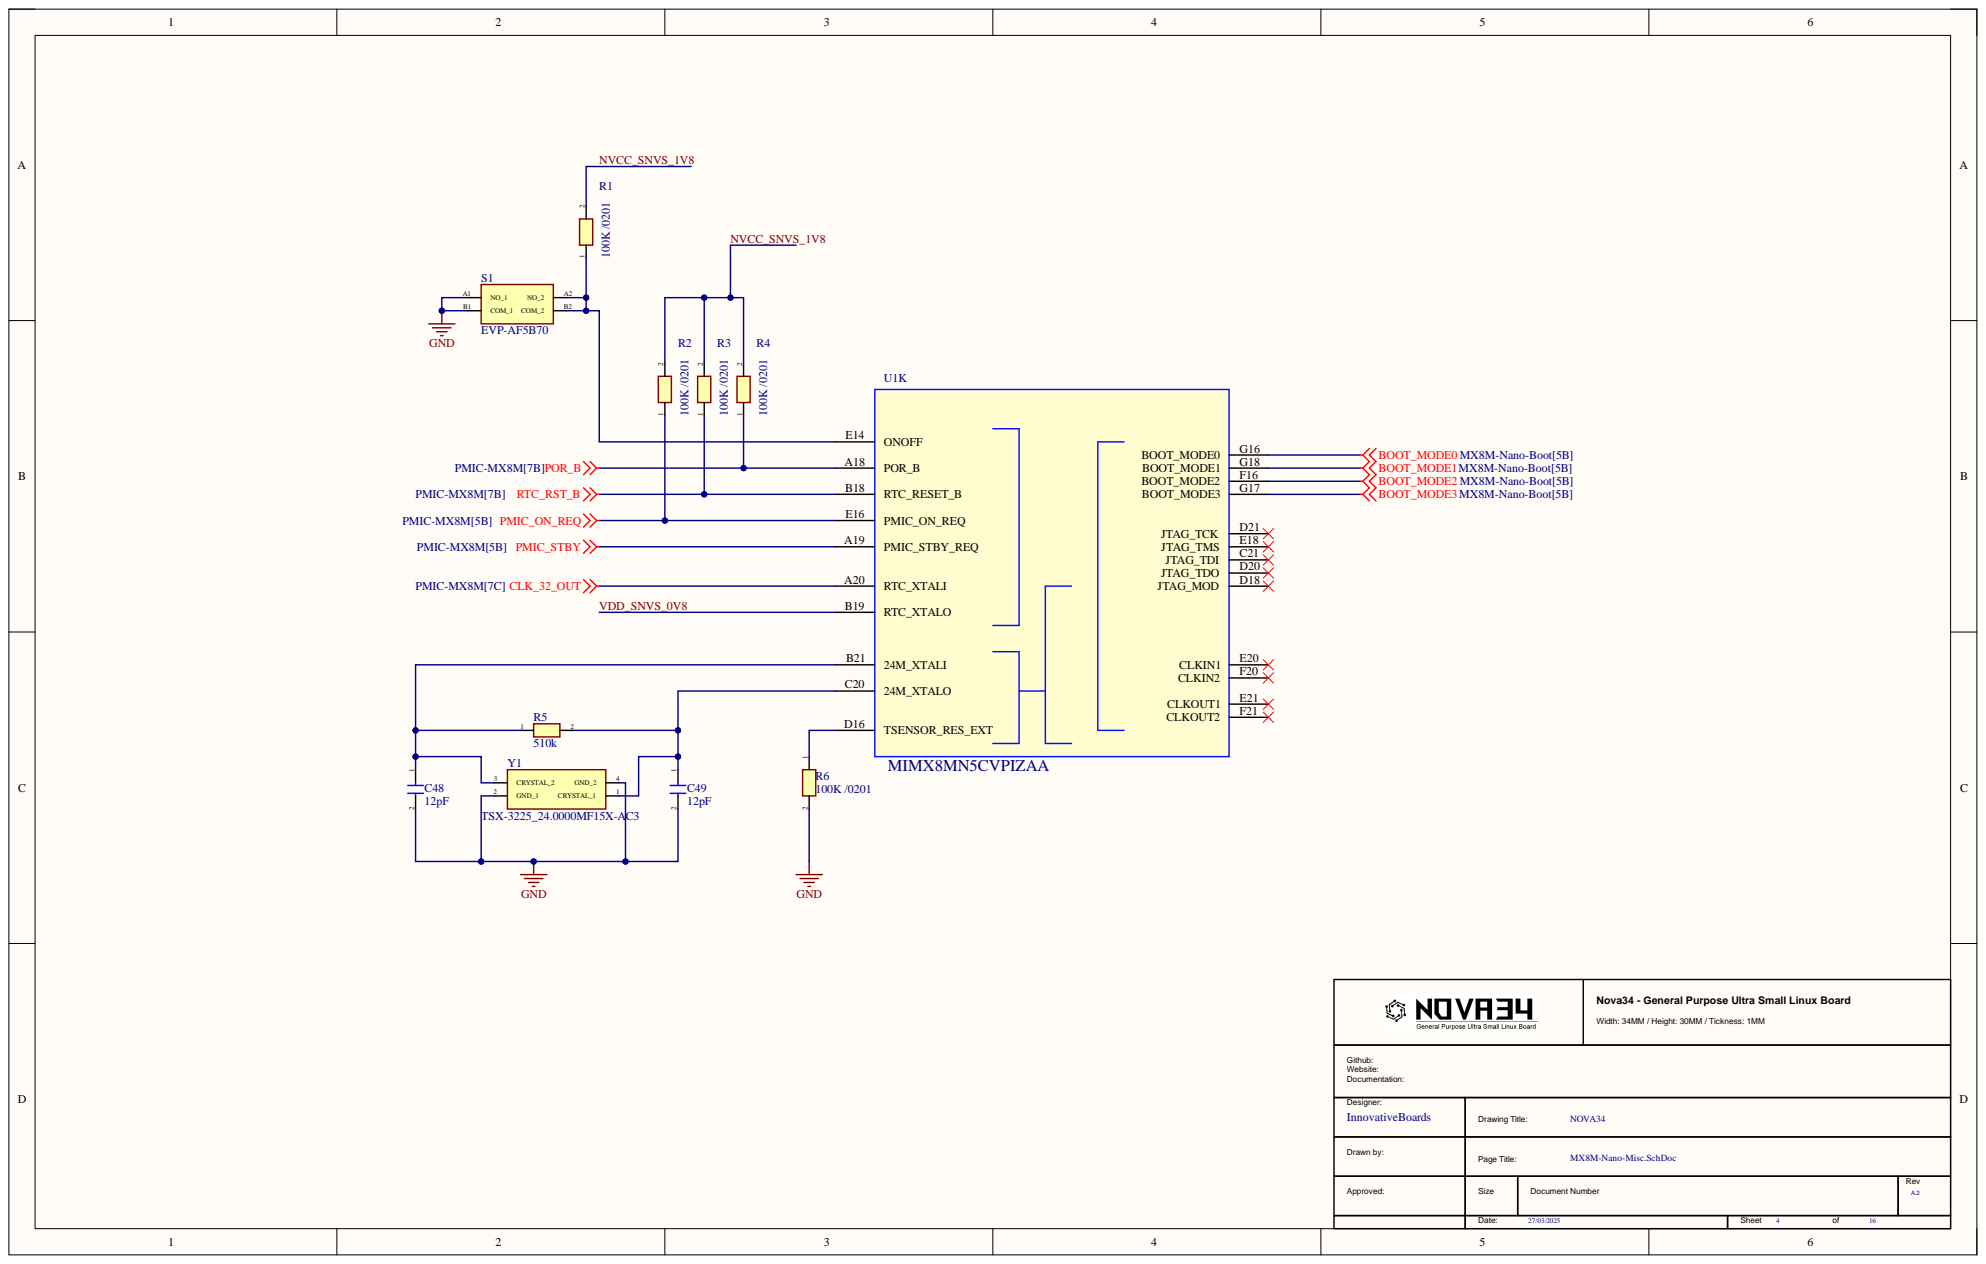
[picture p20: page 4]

Nova34 - General Purpose Ultra Small Linux Board

Designer: InnovativeBoards | Drawing Title: NOVA34

Drawn by: | Page Title: MX8M-Nano-Misc.SchDoc

Approved: | Size | Document Number | Rev A.2

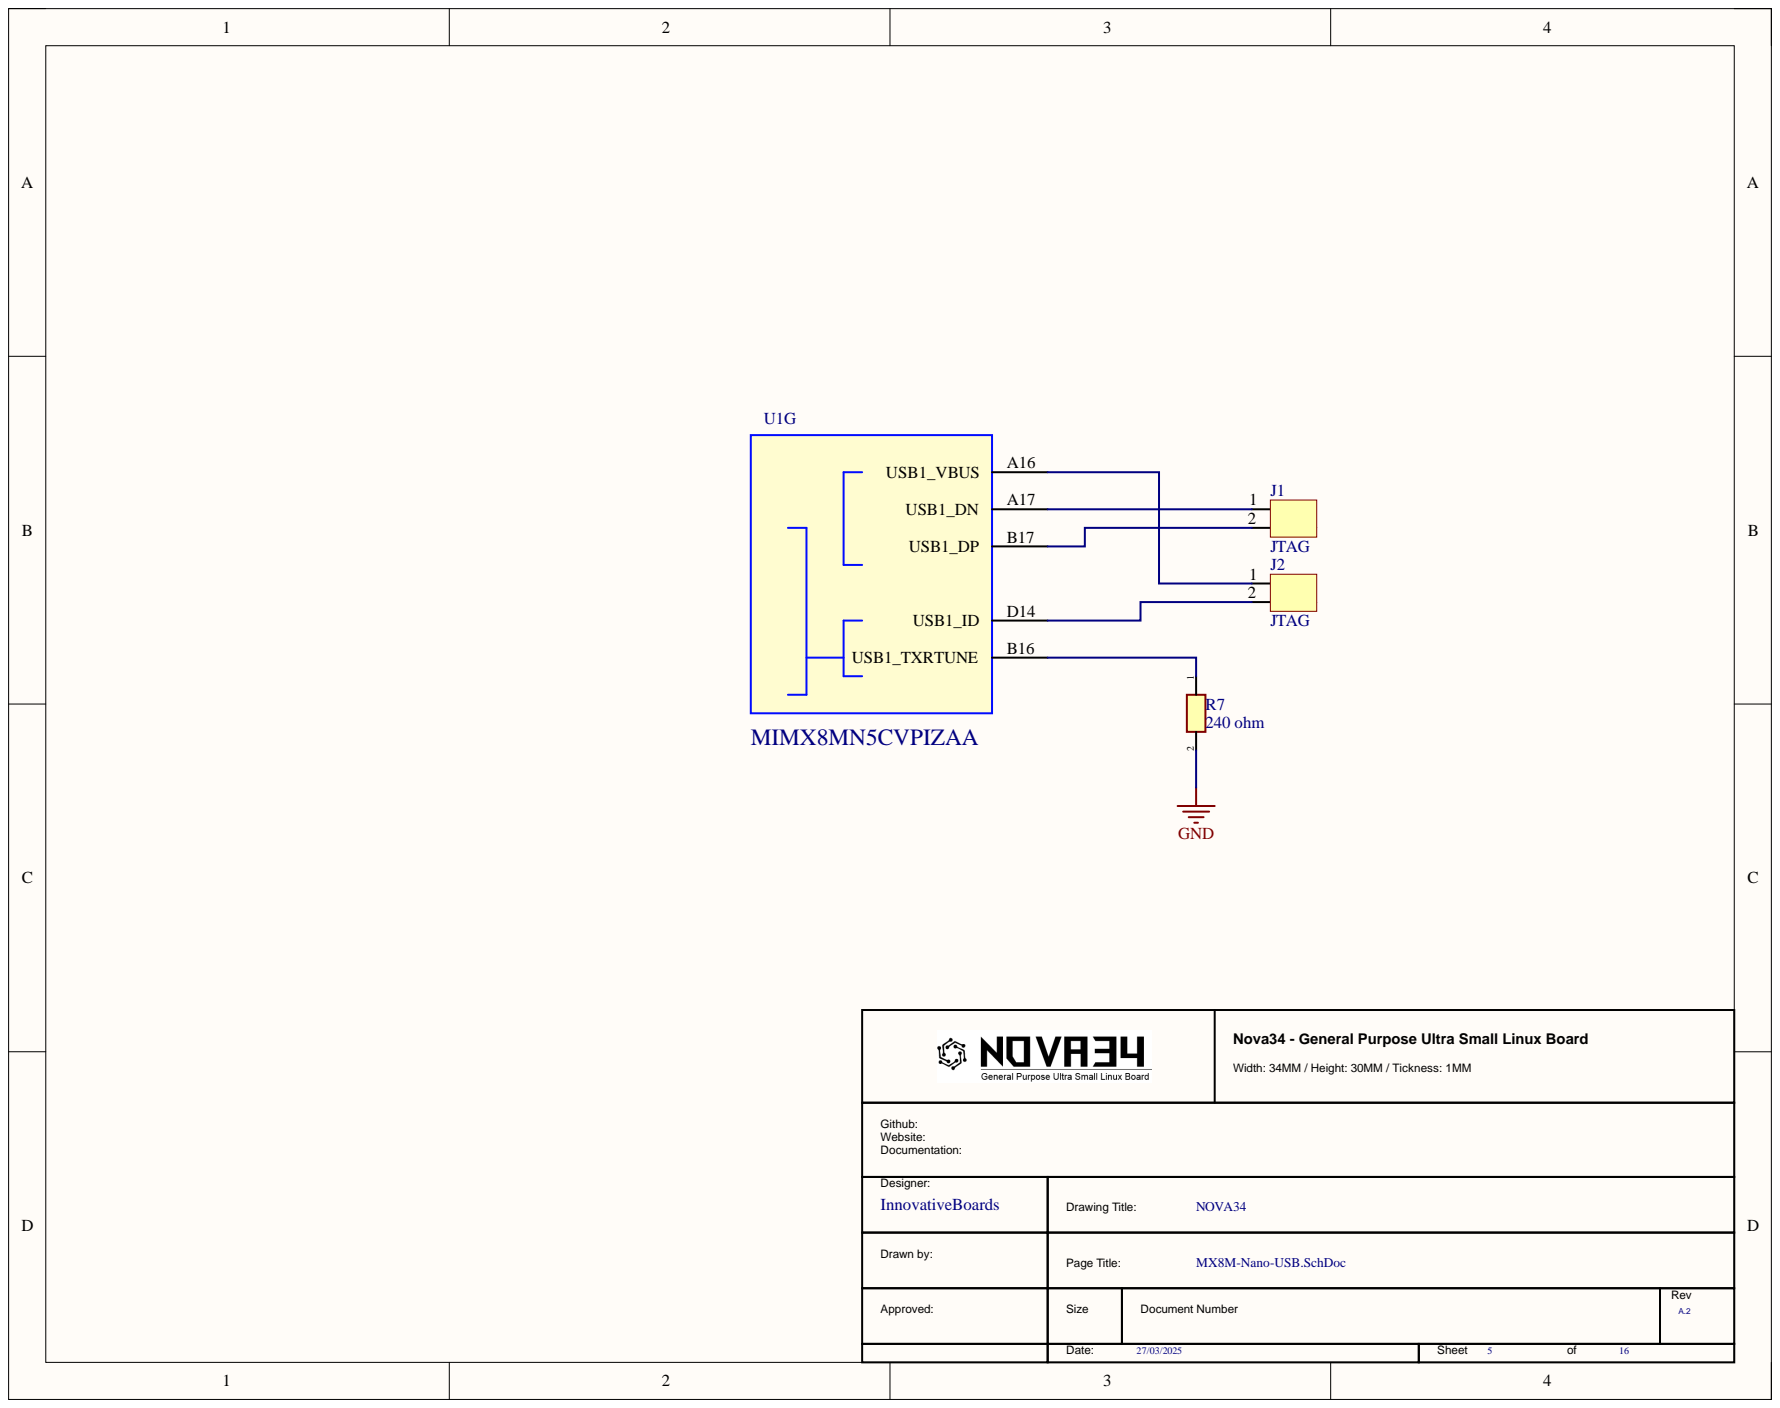
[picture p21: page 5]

Nova34 - General Purpose Ultra Small Linux Board

Designe r : InnovativeBoa rds | Drawing Title: NOVA3 4

Drawn by : | Page Title: MX8M-Nan o -USB.SchDo c

Approv e d : | Siz e | Document Number | Re v

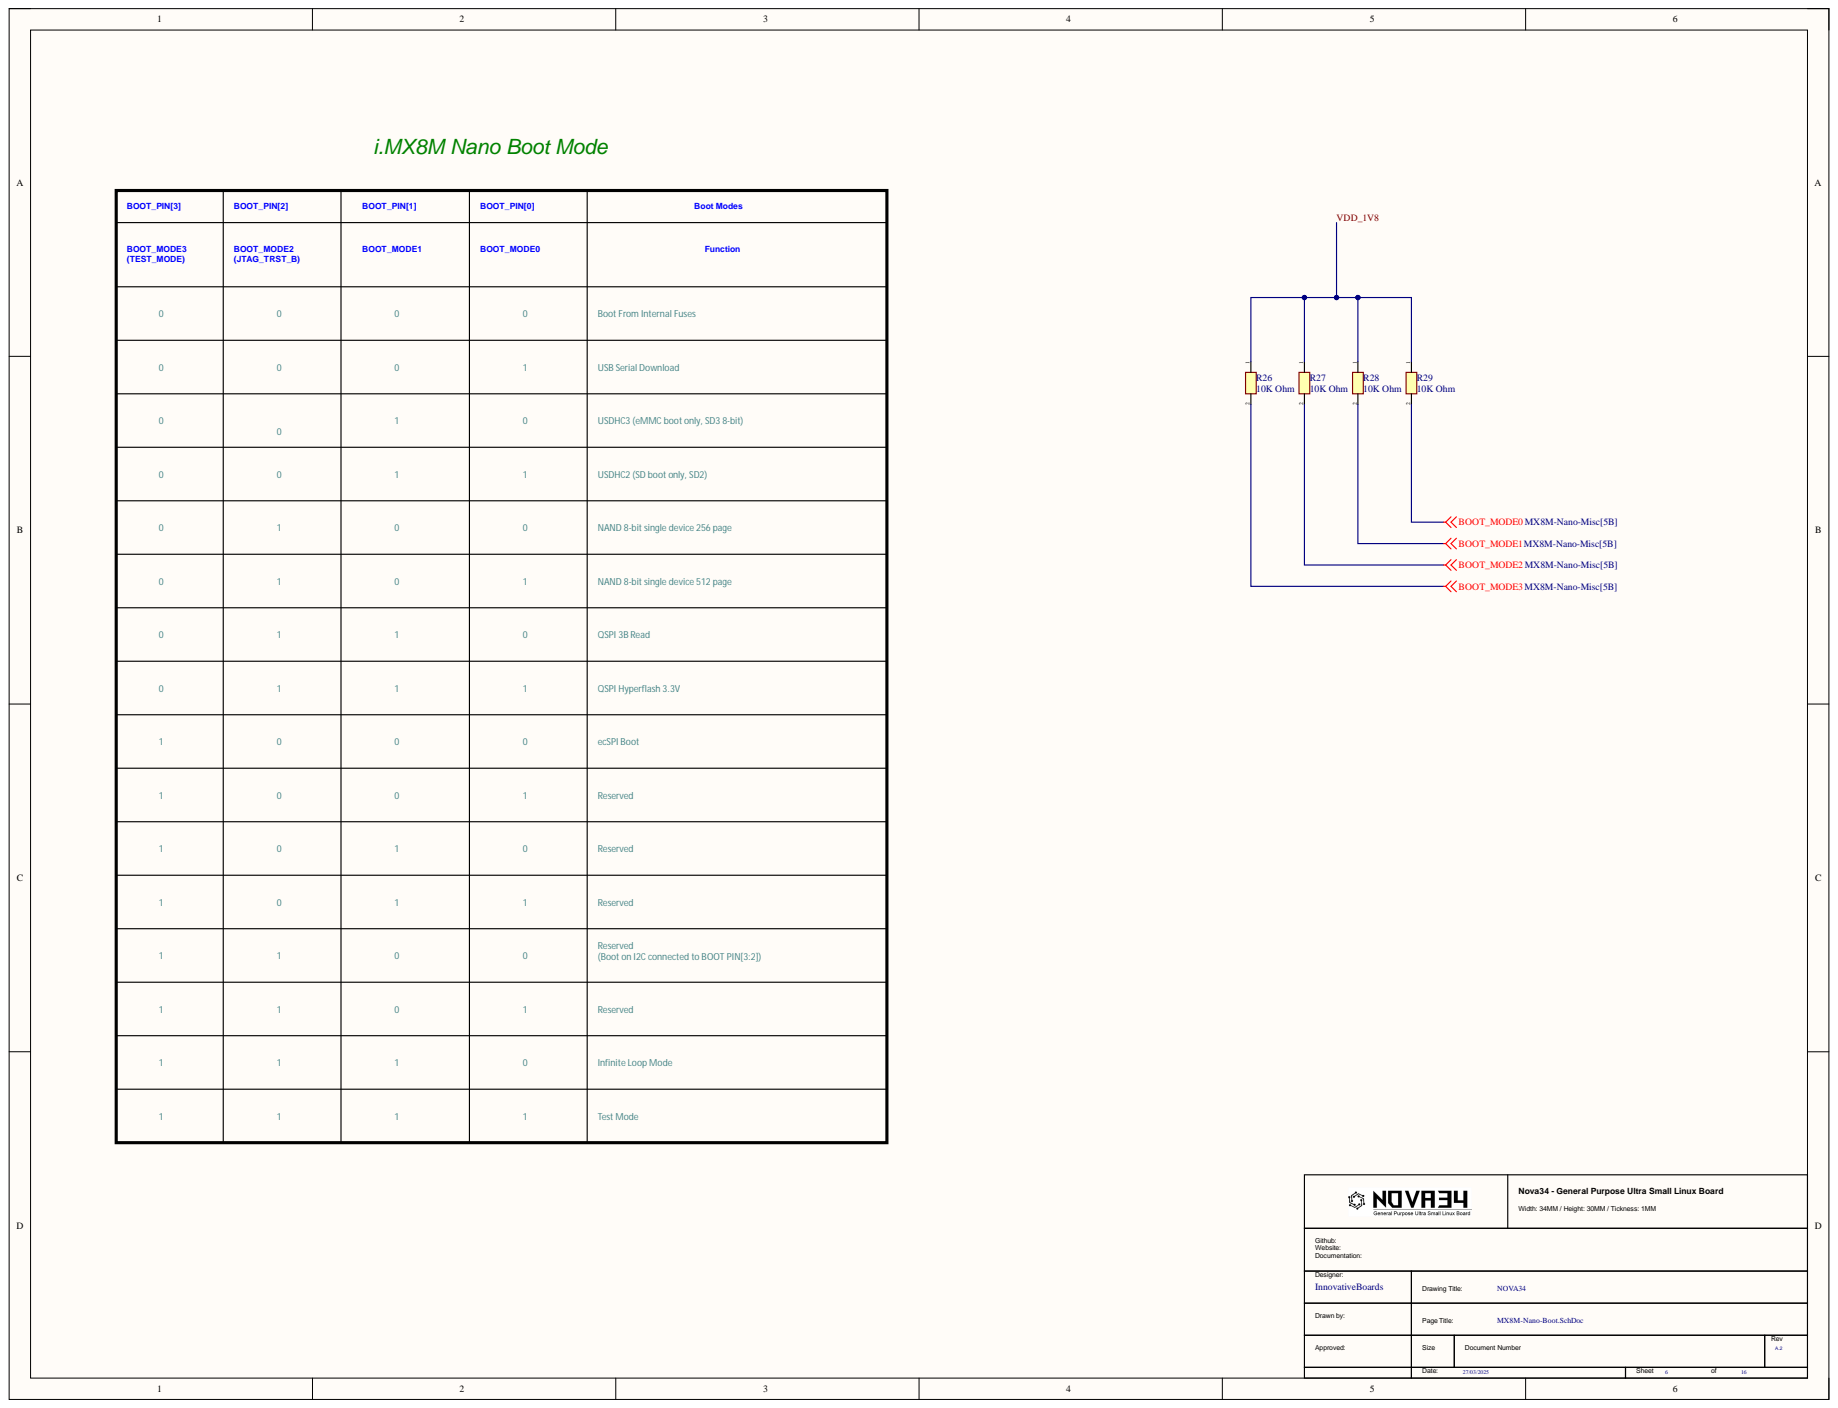
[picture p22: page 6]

BOOT_PIN[3] | BOOT_PIN[2] | BOOT_PIN[1] | BOOT_PIN[0] | Boot Modes

BOOT_MODE3 (TEST_MODE) | BOOT_MODE2 (JTAG_TRST_B) | BOOT_MODE1 | BOOT_MODE0 | Function

0 | 0 | 0 | 0 | Boot From Internal Fuses

0 | 0 | 0 | 1 | USB Serial Download

0 | 0 | 1 | 0 | USDHC3 (eMMC boot only, SD3 8-bit)

0 | 0 | 1 | 1 | USDHC2 (SD boot only, SD2)

0 | 1 | 0 | 0 | NAND 8-bit single device 256 page

0 | 1 | 0 | 1 | NAND 8-bit single device 512 page

0 | 1 | 1 | 0 | QSPI 3B Read

0 | 1 | 1 | 1 | QSPI Hyperflash 3.3V

1 | 0 | 0 | 0 | ecSPI Boot

1 | 0 | 0 | 1 | Reserved

1 | 0 | 1 | 0 | Reserved

1 | 0 | 1 | 1 | Reserved

1 | 1 | 0 | 0 | Reserved (Boot on I2C connected to BOOT PIN[3:2])

1 | 1 | 0 | 1 | Reserved

1 | 1 | 1 | 0 | Infinite Loop Mode

1 | 1 | 1 | 1 | Test Mode

Nova34 - General Purpose Ultra Small Linux Board

Designer: InnovativeBoards | Drawing Title: NOVA34

Drawn by: | Page Title: MX8M-Nano-Boot.SchDoc

Approved: | Size | Document Number | Rev

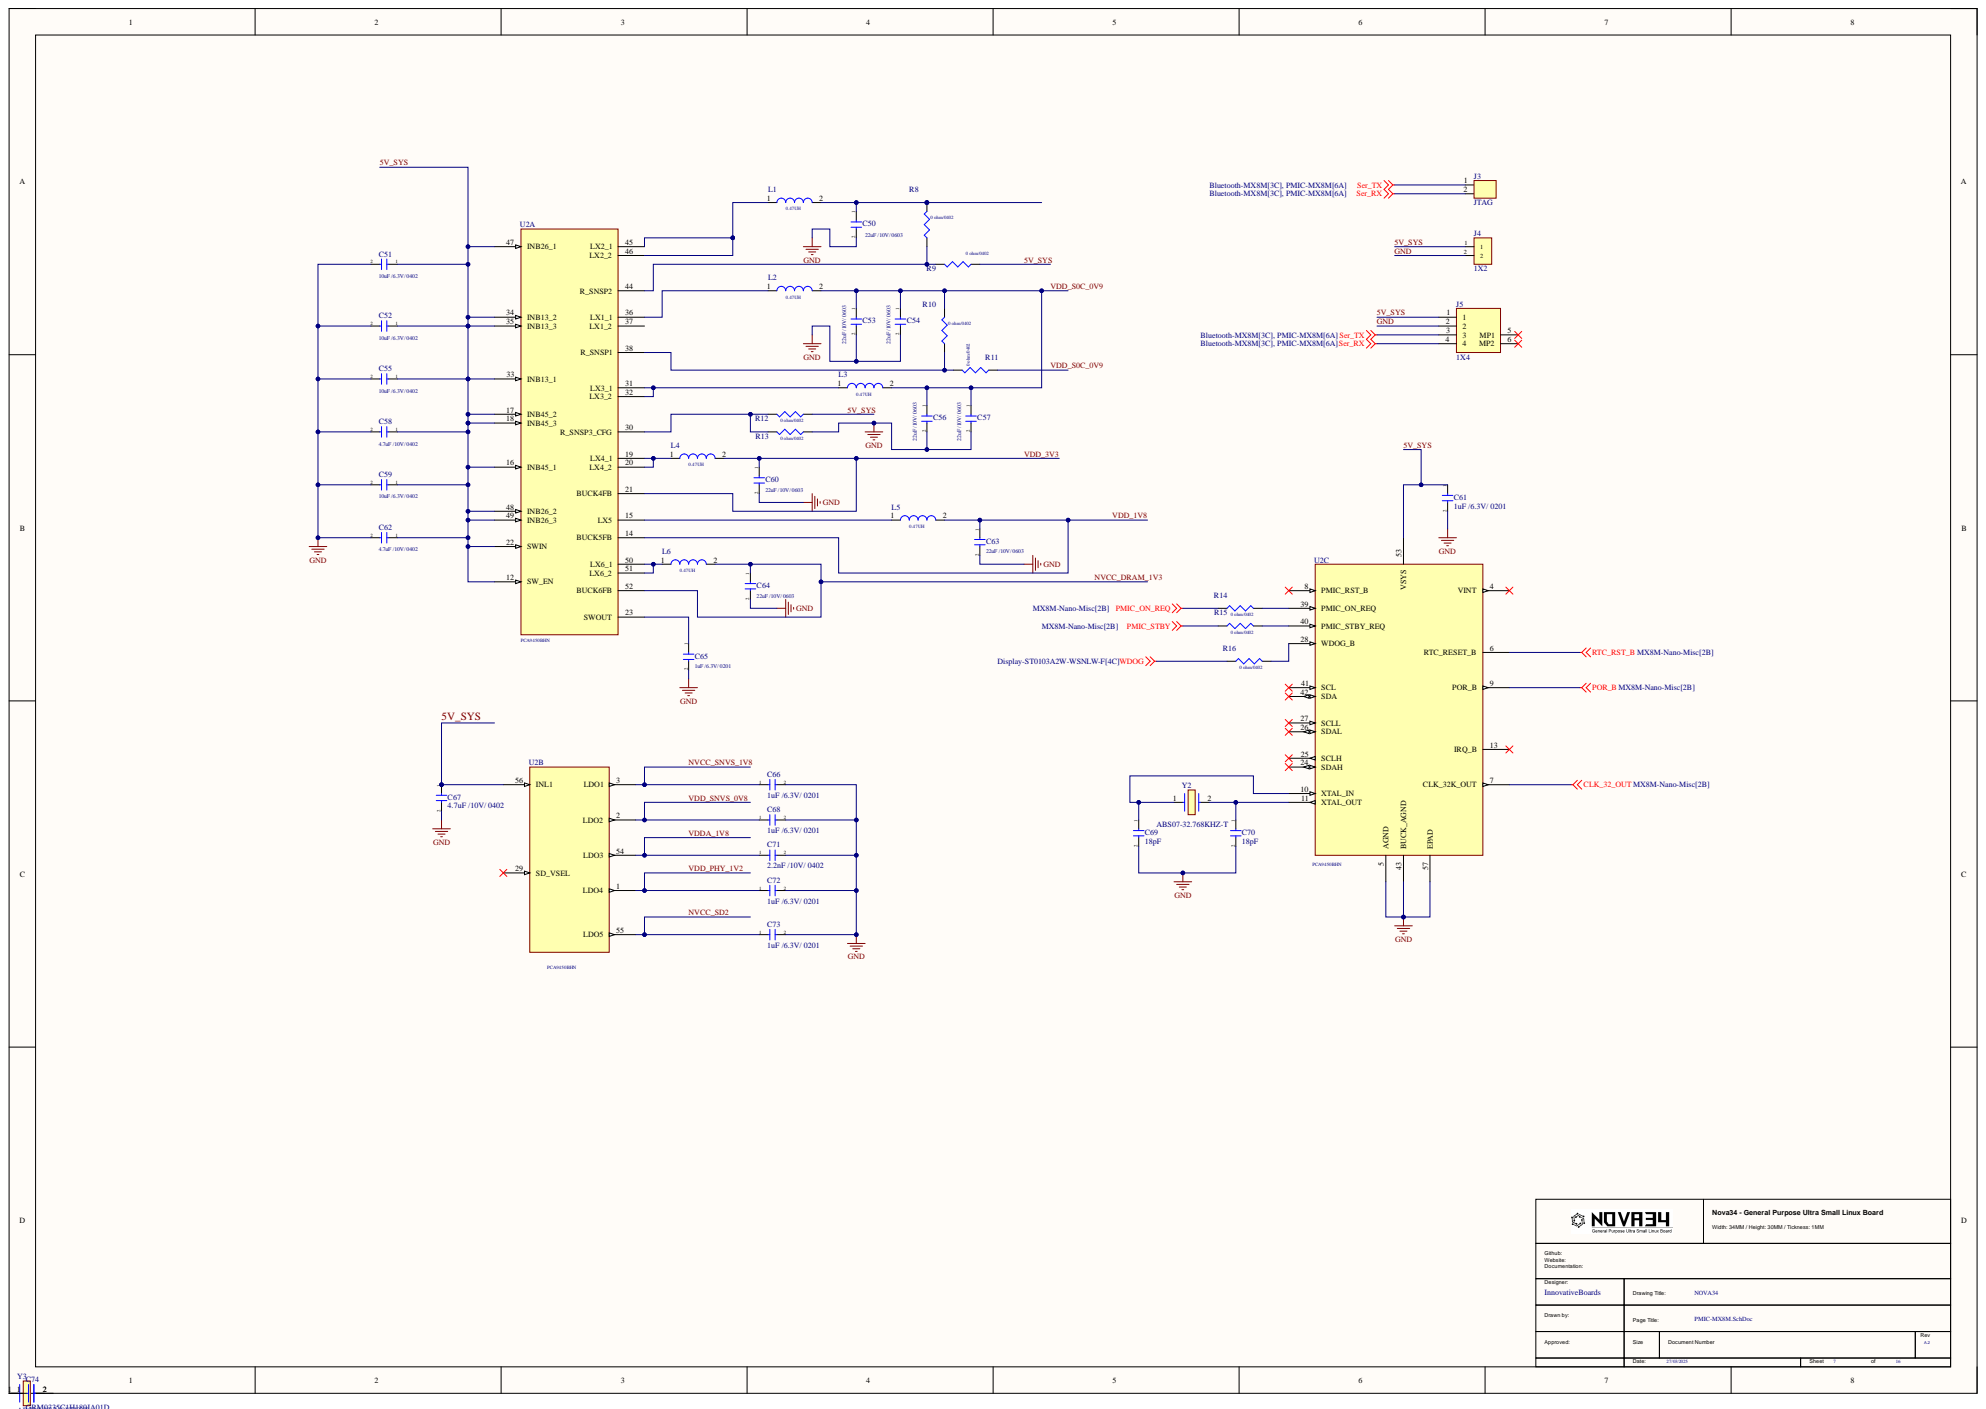
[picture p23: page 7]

Nova34 - General Purpose Ultra Small Linux Board

Designer: InnovativeBoards | Drawing Title: NOVA34

Drawn by: | PMIC-MX8M.SchDoc Page Title:

Approved: | Size | Document Number | Rev

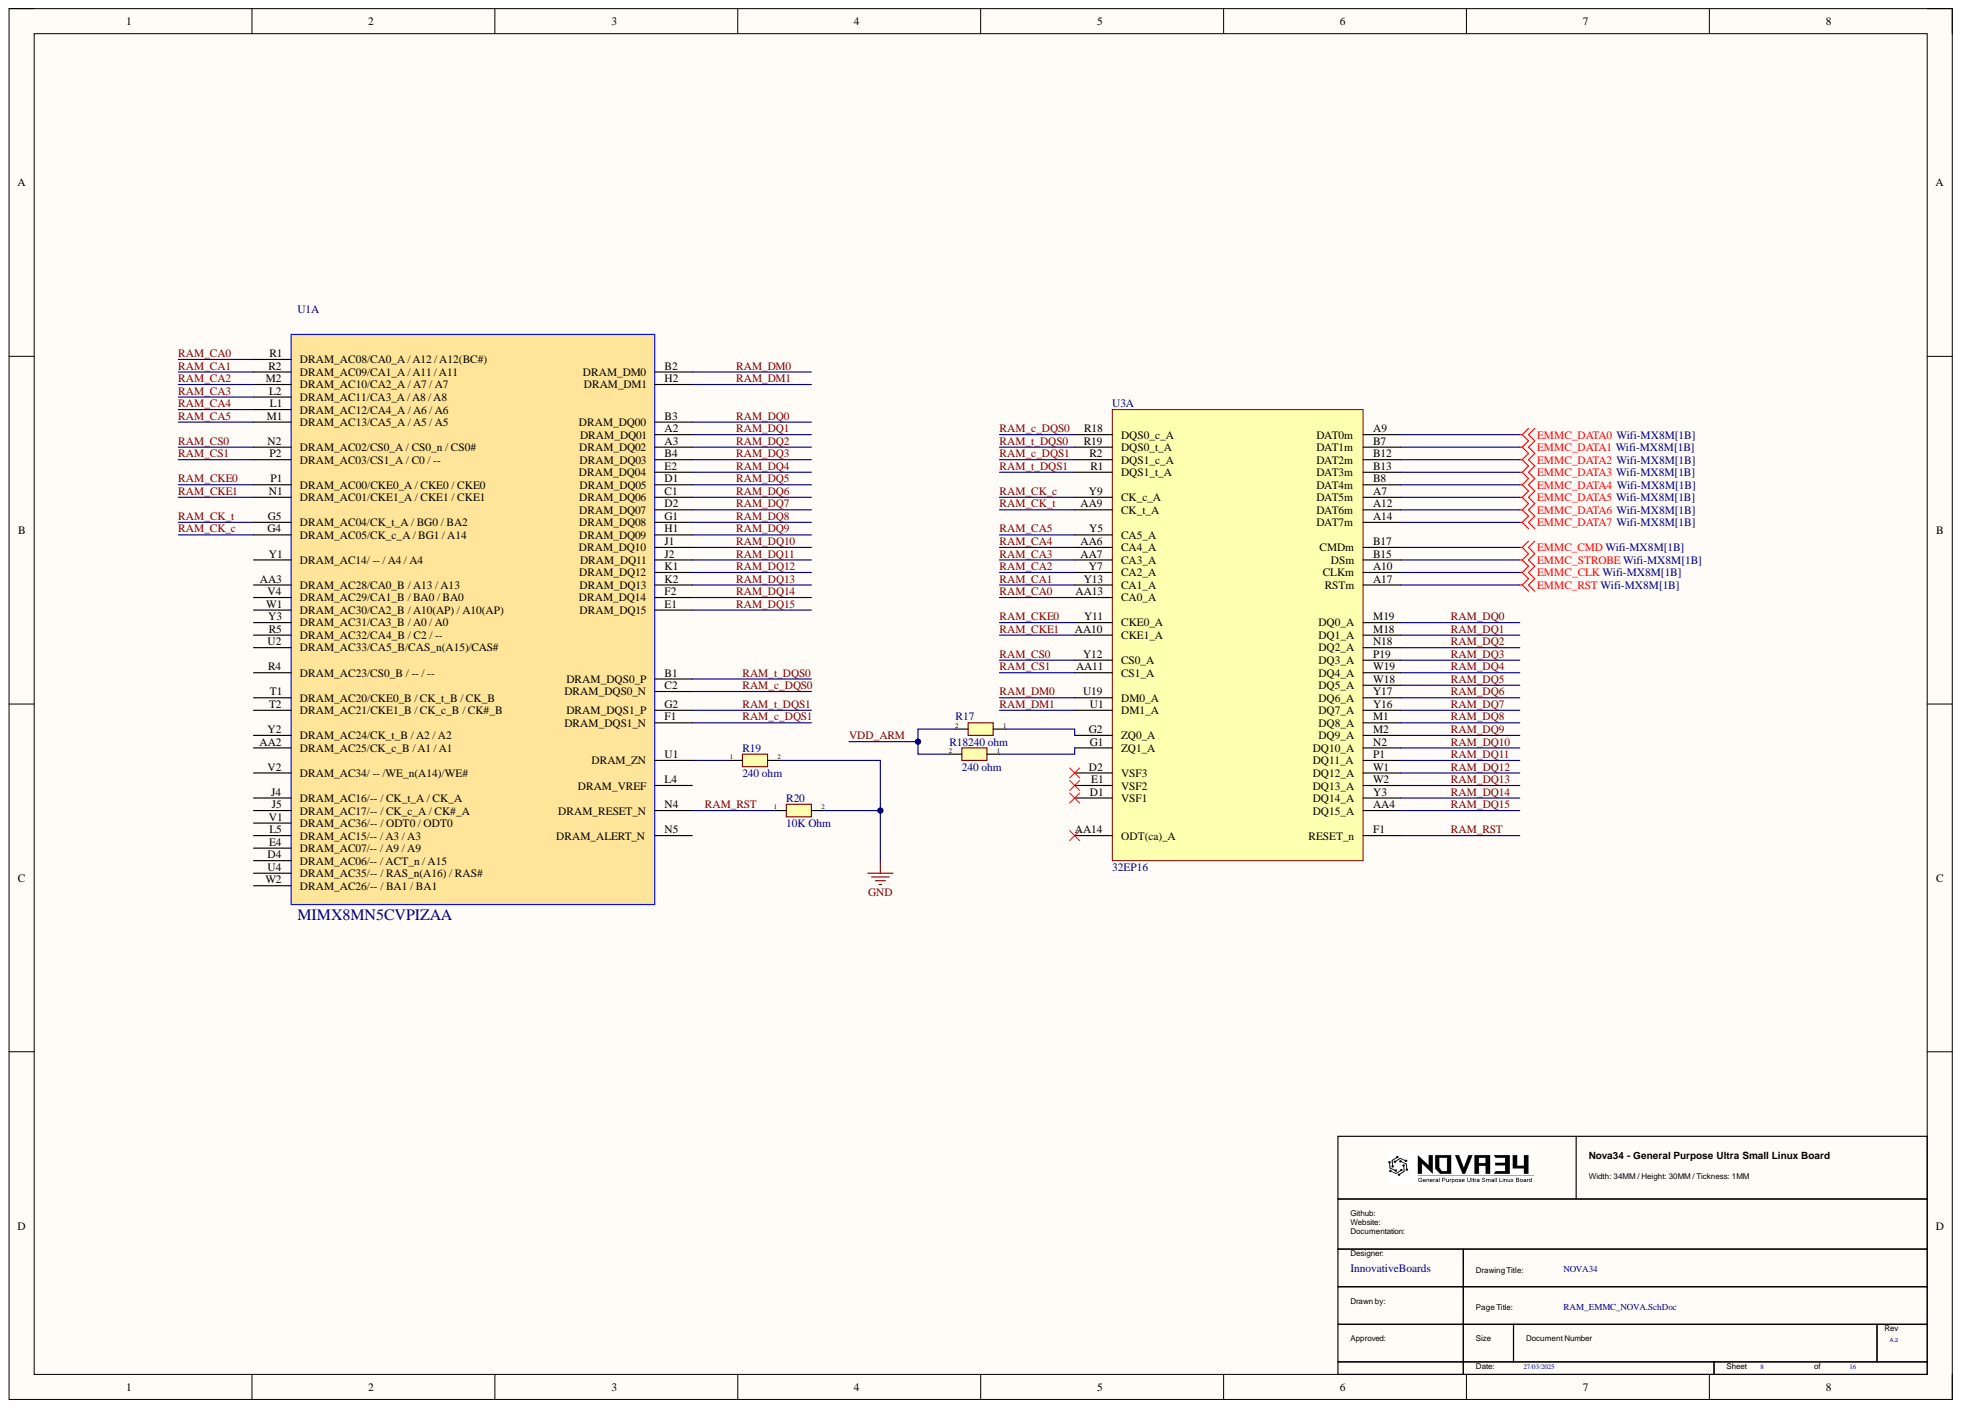
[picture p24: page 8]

Desig n e r : InnovativeBoar d s | Dr awin g Title : NOVA34 RAM_EM

Dr awn by: | P a g e Title : M C_NOVA.SchDoc

A p p r o v e d : | Siz e | Docu m e nt Nu m b e r | Re v A .

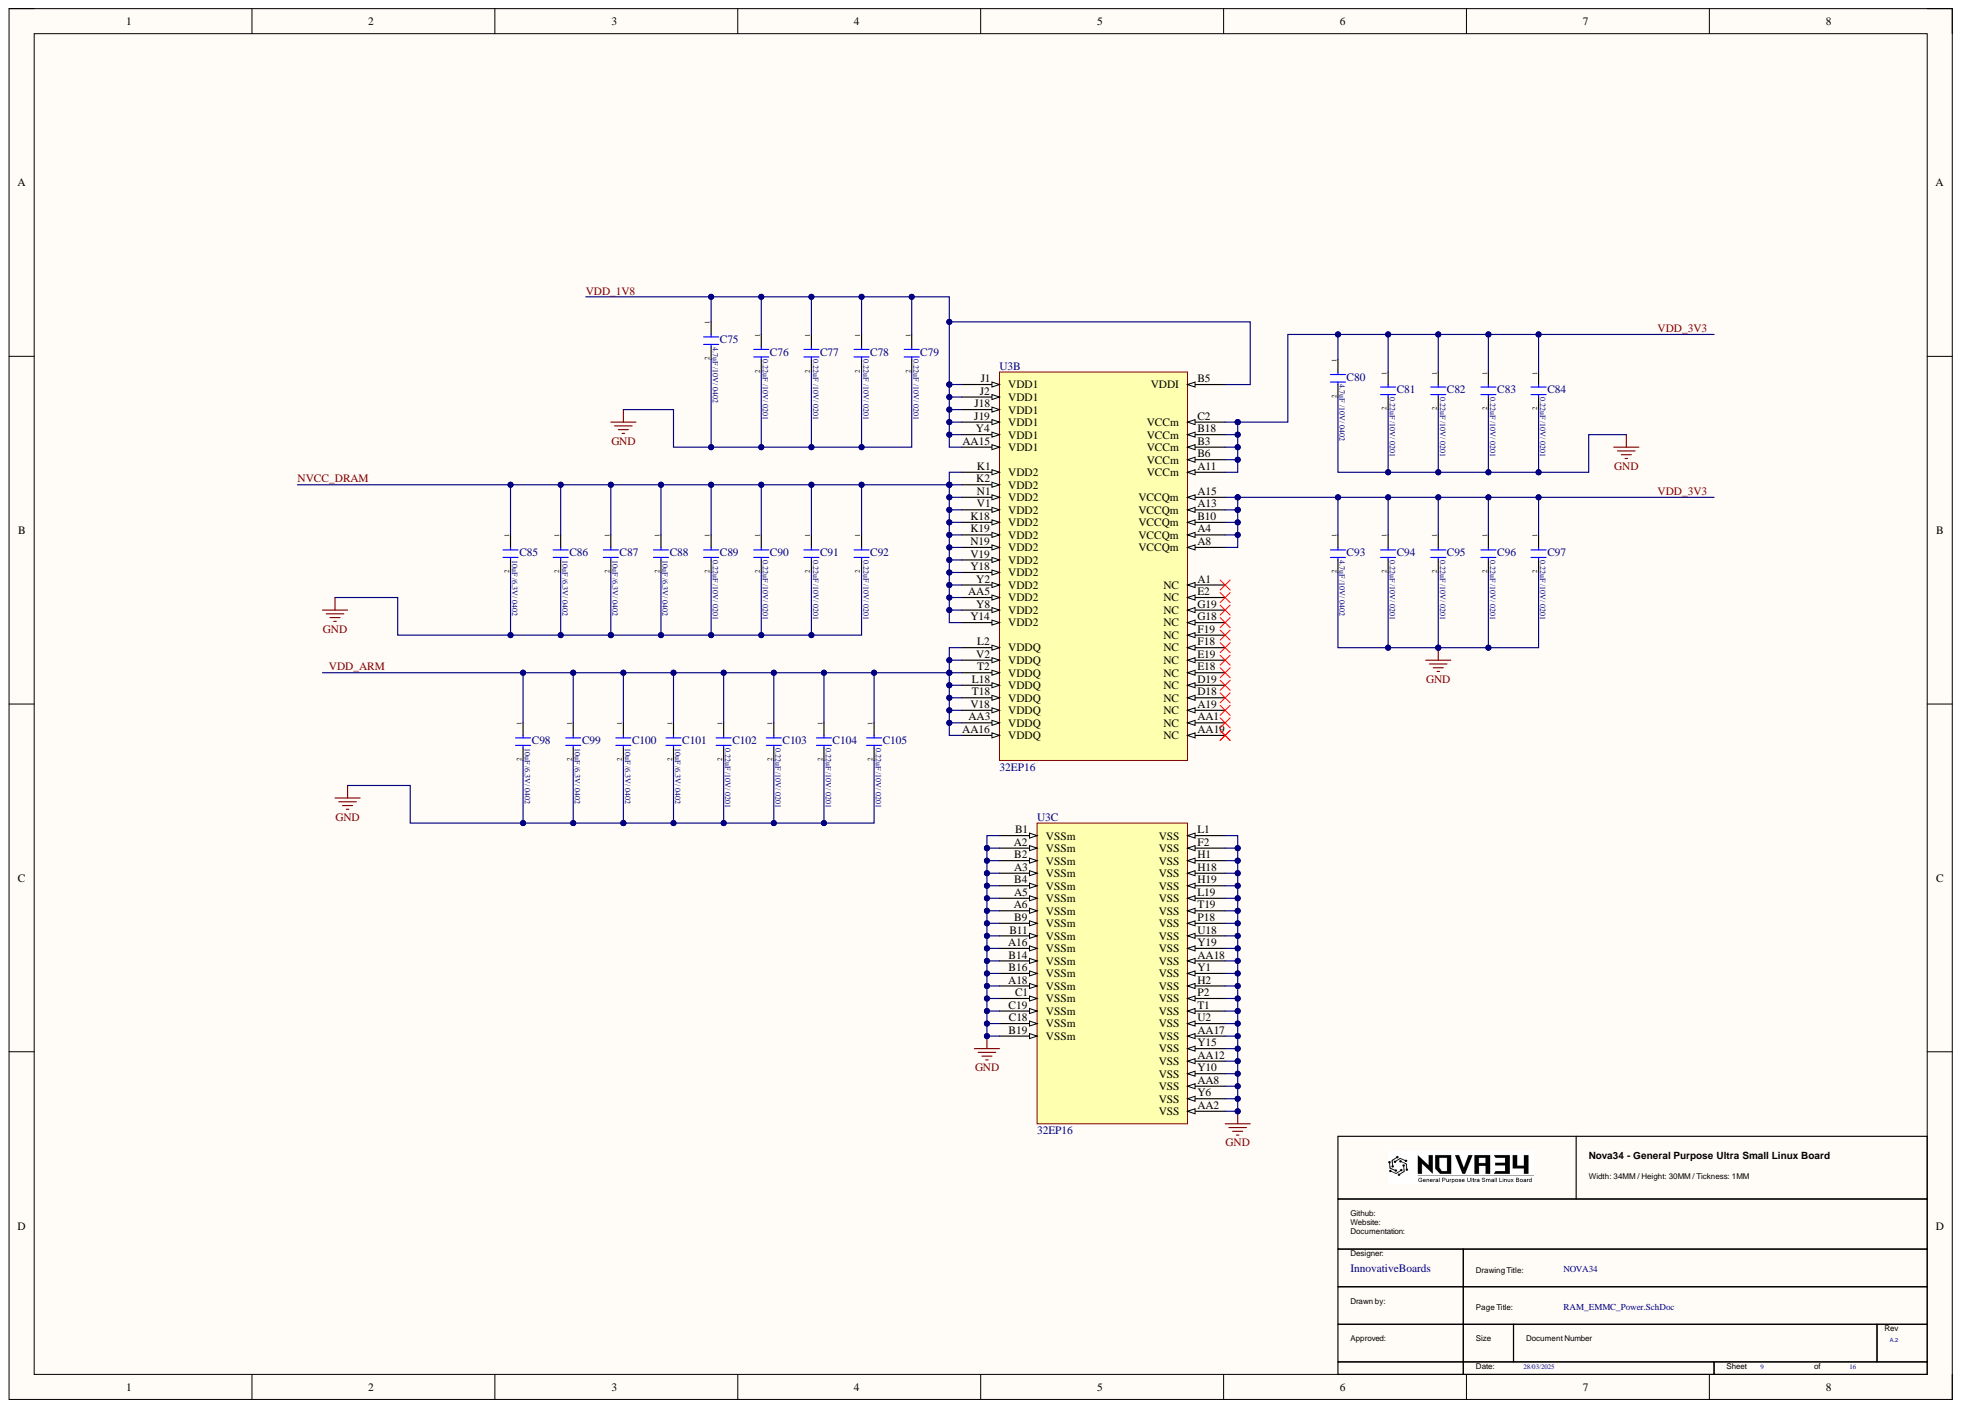
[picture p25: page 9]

Nova34 - General Purpose Ultra Small Linux Board

Designer: InnovativeBoards | Drawing Title: NOVA34

Drawn by: | Page Title: RAM_EMMC_Power.SchDoc

Approved: | Size | Document Number | Rev

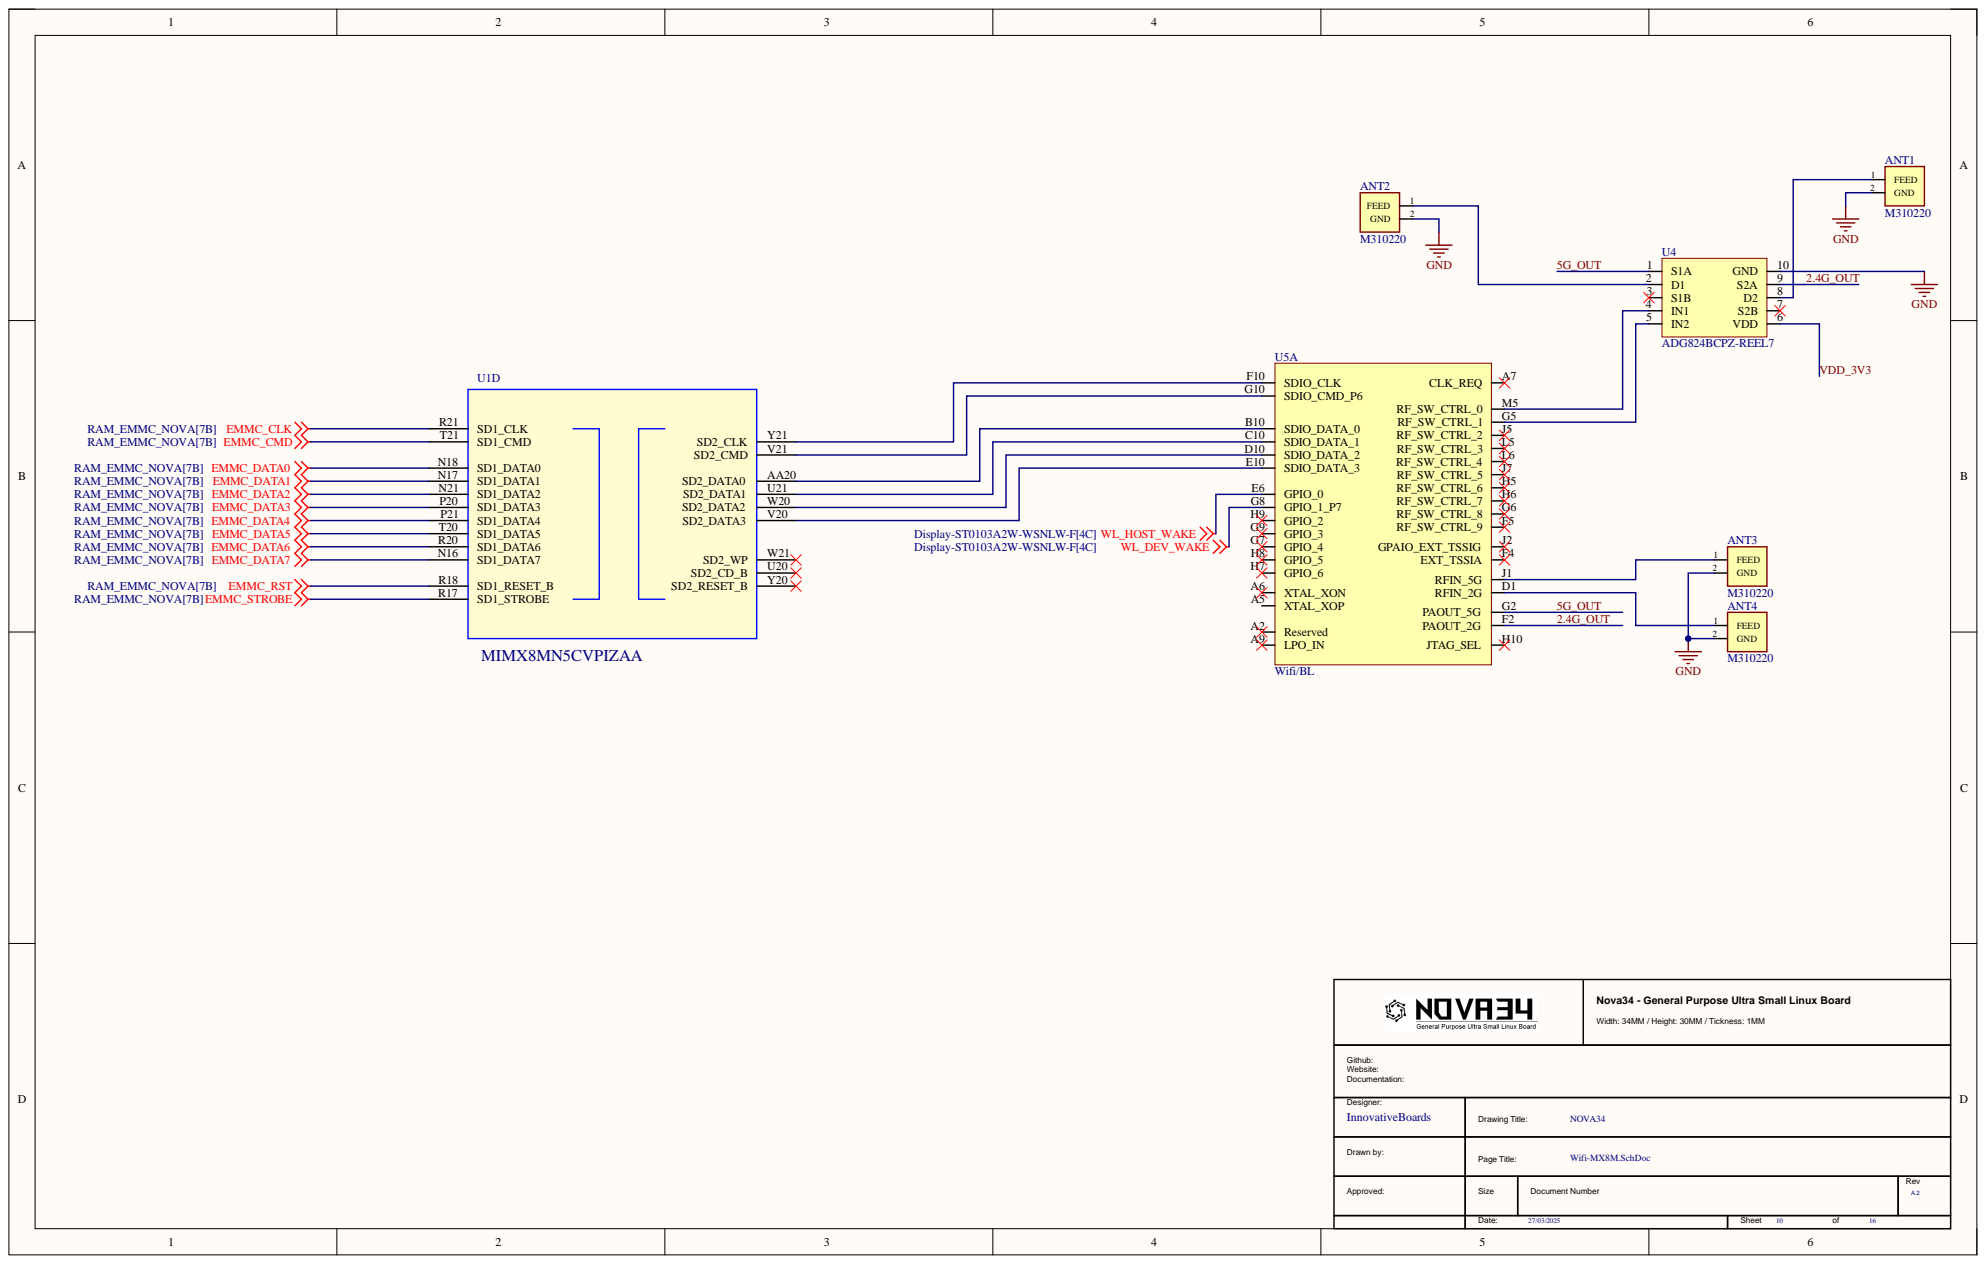
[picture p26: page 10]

K R21 SD1_CMD T21 0 N18 1 N17 2 N21 3 P20 TA4 P21 5 T20 6 R20 7 N16 _B R18 E R17

GPIO_2 H9

Des igner : InnovativeBo ar d s | Drawing T itle: NOVA3 4

Drawn by : | Page T itle: Wifi-MX8 M.S c hDo c

Approved: | S i z e | Document Number | Re v A. 2

Date: | Sheet of

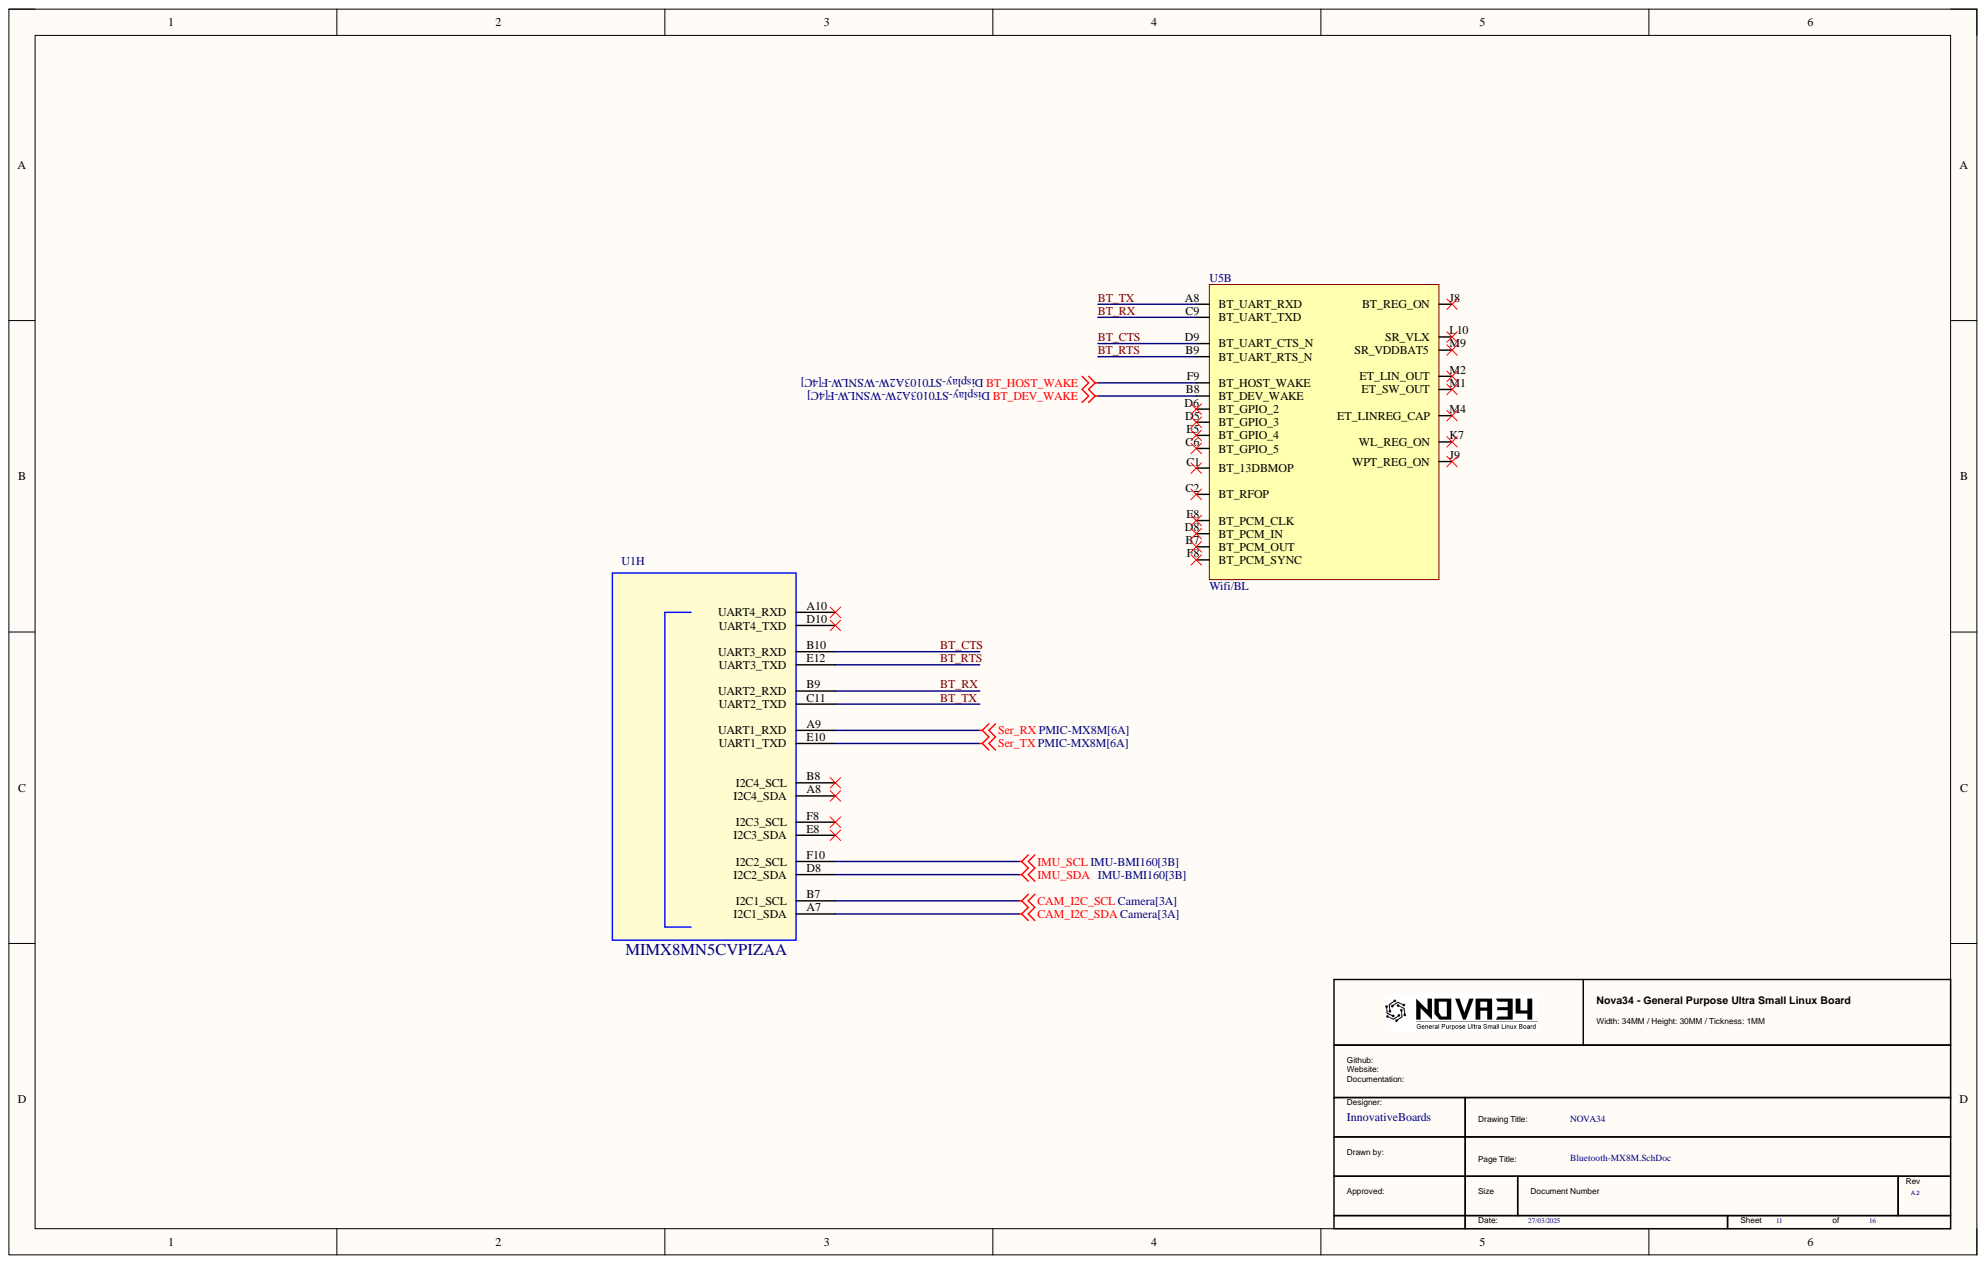
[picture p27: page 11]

Des igner : InnovativeBo ar d s | Drawing T itle: NOVA3 4

Drawn by : | Page T itle: Blu eto oth-MX8 M.S c hDo c

Approved: | S i z e | Document Number | Re v A. 2

Date: | Sheet of

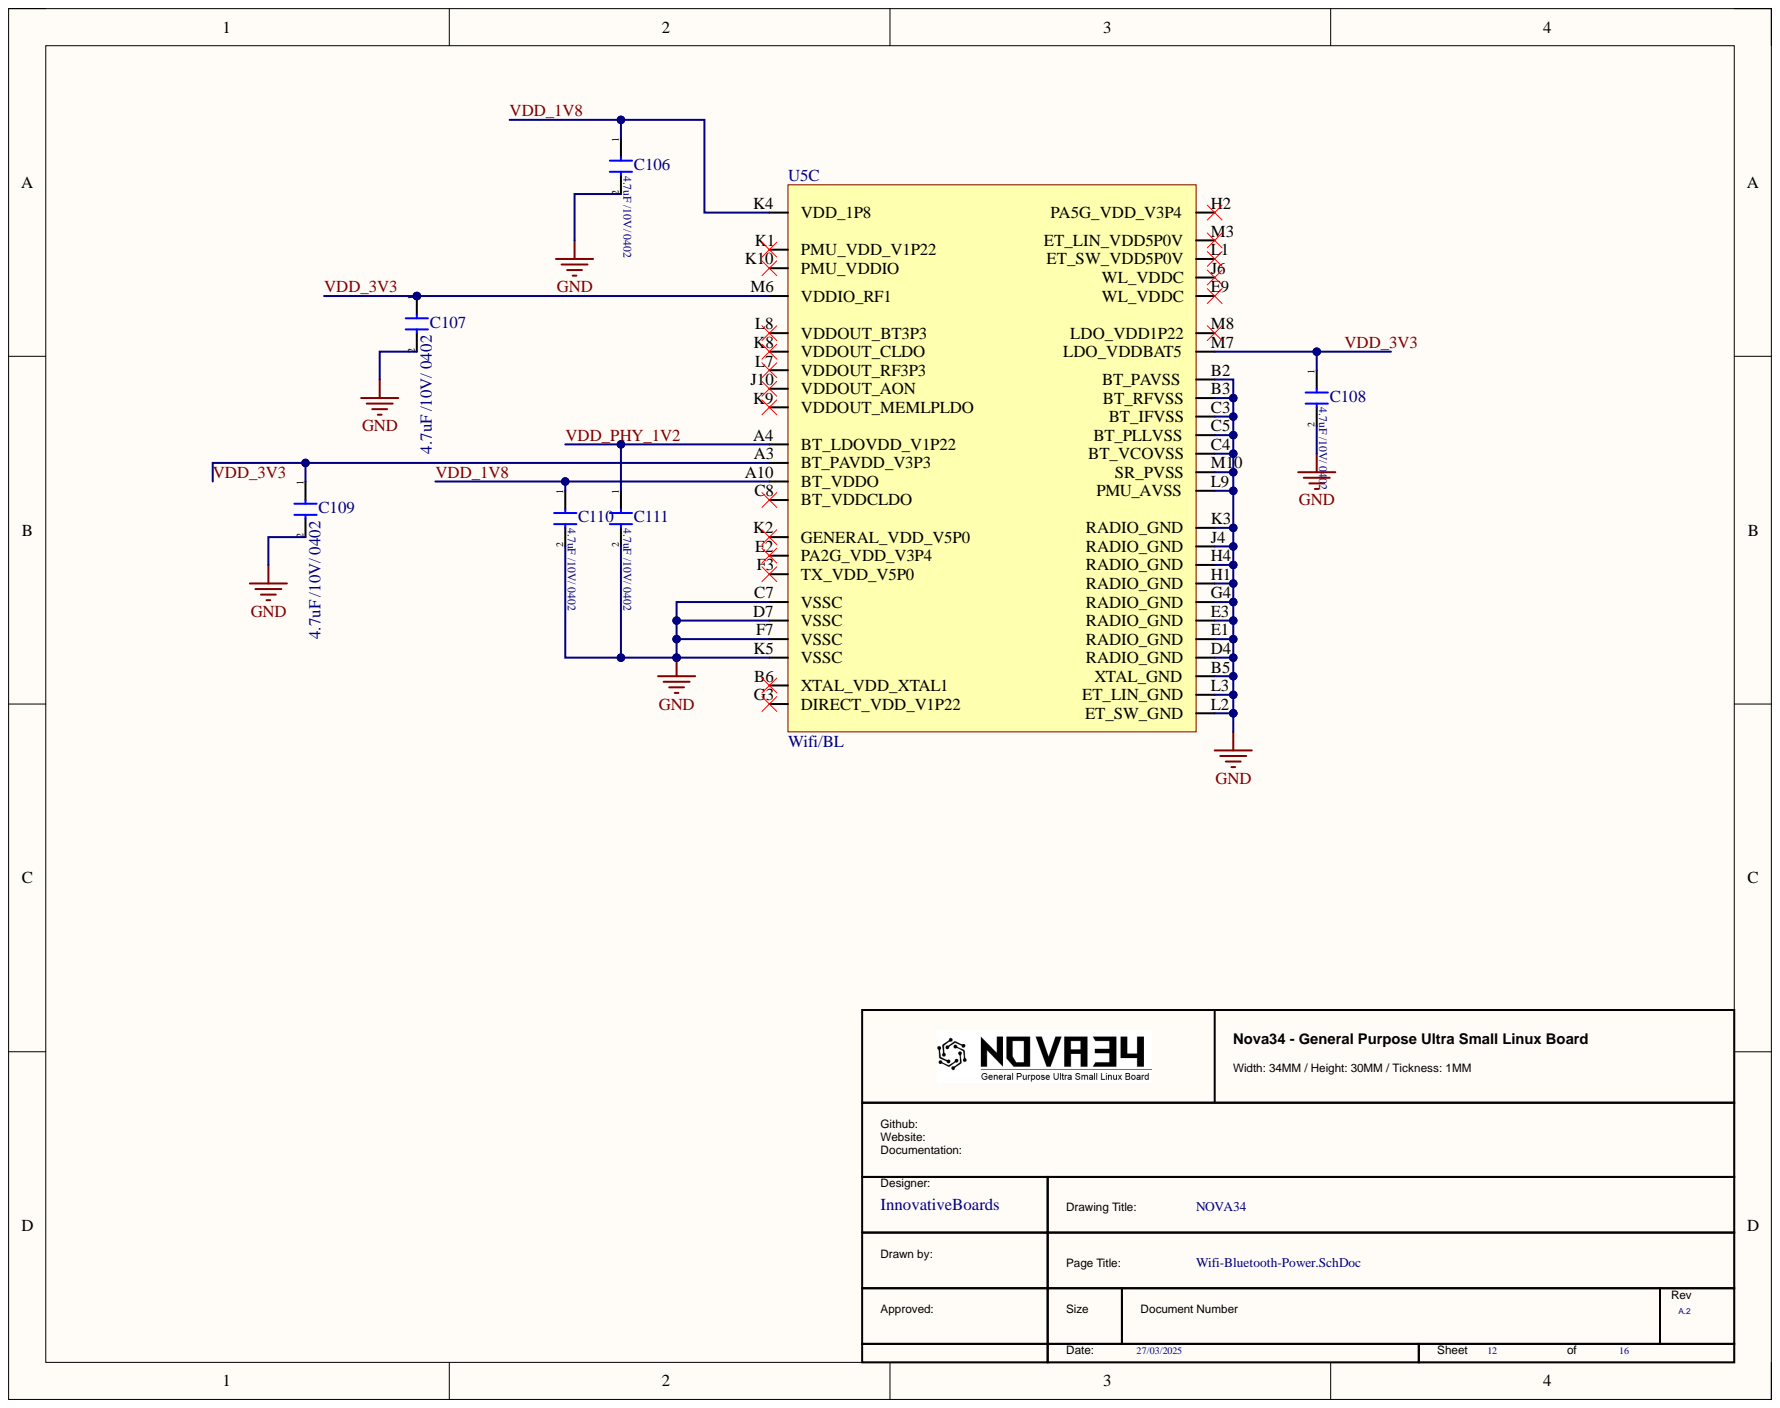
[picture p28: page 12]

Nova34 - General Purpose Ultra Small Linux Board

Designe r : InnovativeBoa rds | Drawing Title: NOVA3 4

Drawn by : | Page Title: Wifi-Blueto oth -Power.SchDo c

Approv e d : | Siz e | Document Number | Re v


Nova34 - General Purpose Ultra Small Linux Board

Designe r : InnovativeBoa rds | Drawing Title: NOVA3 4

Drawn by : | Page Title: IMU-BMI 1 6 0.SchDo c

Approv e d : | Siz e | Document Number | Re v


GND 1 GND 2 WRX 3 SDA 4 SDO 5 DCX 6 CSX 7 RESX 8 lOVCC 9 lOVCC 10 VCC 11 VCC 12 GND 13 GND 14 N/C 15 N/C 16 LEDK1 17 LEDK2 18 LEDA 19 LEDA 20 ST0103A2W-WSNLW-F

Nova34 - General Purpose Ultra Small Linux Board

Designer: InnovativeBoards | Drawing Title: NOVA34

Drawn by: | Page Title: Display-ST0103A2W-WSNLW-F.SchDoc

Approved: | Size | Document Number | Rev A.2


Nova34 - General Purpose Ultra Small Linux Board
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

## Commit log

2024-08-22 First Setup
    [32EP16.SchLib, B4B-ZR-SM4-TFT-LF--SN---3DModel-STEP-740395.STEP, BGA144C80P12X12_1000X1000X140N.PcbLib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]
2025-03-08 Fix: rimosso il riferimento ai submoduli e aggiunte come normali directory
    [IMPORT PCB1.PcbLib, Page01 COVER.SchDoc, Page02 BLOCK DIAGRAM.SchDoc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]
2025-03-28 Aggiunto nova34_docs come submodulo in docs
    [Cover-Page.SchDoc, NOVA-Block.SchDoc, Nova_34.PrjPcb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]
2025-03-31 add document xls components
    [32EP16.SchLib, B4B-ZR-SM4-TFT-LF--SN---3DModel-STEP-740395.STEP, BGA144C80P12X12_1000X1000X140N.PcbLib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]
2025-04-01 Add ESD Protection
    [Bluetooth-MX8M.SchDoc, Camera.SchDoc, Components.xlsx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]

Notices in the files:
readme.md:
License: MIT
